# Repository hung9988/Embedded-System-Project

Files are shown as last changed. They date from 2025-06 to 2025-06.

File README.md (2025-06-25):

# HUST Embedded Systems Project
This is a project for the course of Embedded Systems at HUST.

## Project Overview
This project focus on the design of a analog macro pad using the Blackpill (STM32F411CEU6) microcontroller. 

## Features
- **Analog Output**: The macro pad can output analog signals.
- **Rapid Trigger**: A feature that allows the macro pad to send a signal immediately when a key is pressed, without waiting for the key to be released.
- **USB HID**: The macro pad will be recognized as a Human Interface Device (HID) by the host computer, allowing it to send key presses and other input events.
- **USB CDC**: The macro pad will support USB Communication Device Class (CDC) for serial communication with the host computer.
- **Macro Support**: The macro pad can be programmed to perform specific actions when certain keys are pressed.
## External Links
- [3D Case Design](https://cad.onshape.com/documents/5e6cfea2e32c850f530cae58/w/579554a927bd0a7730e0b539/e/56addd2516469d5755cfe071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)

## Resources

- [How does USB work?](https://www.youtube.com/watch?v=N0O5Uwc3C0o&t=158s)
- [What is Rapid Trigger?](https://www.youtube.com/watch?v=eZENx1T7OLw)

## References

- [Minipad](https://github.com/minipadKB/minipad-firmware)
- [Riskeyboard](https://github.com/riskable/void_switch_65_pct)
- [Macrolev](https://github.com/heiso/macrolev/tree/main)
- [TinyUSB](https://github.com/hathach/tinyusb)
- [USB in a Nutshell](https://www.beyondlogic.org/usbnutshell/usb1.shtml)
- [SSD1306](https://github.com/afiskon/stm32-ssd1306/tree/master)

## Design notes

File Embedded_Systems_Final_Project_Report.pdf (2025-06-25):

HANOI UNIVERSITY OF SCIENCE AND TECHNOLOGY

SCHOOL OF INFORMATION AND COMMUNICATION TECHNOLOGY

### HE16: Hall-Effect Keyboard

EMBEDDED SYSTEMS

COURSE: IT4210E — CLASS CODE: 156819 — SEMESTER 2024.2

Le Ngoc Quang Hung | 20225975 | hung.lnq225975@sis.hust.edu.vn
Tran Quang Hung | 20226045 | tuan.tp22h6045@sis.hust.edu.vn
Tuong Phi Tuan | 20226069 | tuan.tp226069@sis.hust.edu.vn

Submitted to: Professor Ngo Lam Trung

Hanoi - 2025

Contents

1 Introduction | 3
2 Design | 5
3 Setup and Implementation | 17

Glossary

Term | Definition
Hall-Effect sensor | Sensors that detect magnetic fields and convert them into electrical signals.
Hall-Effect switch | A type of contactless switch that uses a magnet and a Hall effect sensor to detect key presses based on the mag-netic field strength.
Actuation point | The depth at which a keypress is registered/unregistered and a signal is sent to the computer. In mechanical switches, this is the fixed point where metal contacts close the circuit. In Hall-Effect switches, it can be ad-justed via firmware.
HID(Human Interface Device) | A class of devices that interact with humans, like key-boards, mice. In USB, it defines a protocol for such in-teractions.
CDC(Communications Device Class) | A USB class to emulate serial ports, allowing microcon-trollers to communicate via a virtual COM port.
Rapid Trigger | A feature allowing keys to reset and re-register quickly, enabling faster repeated input without returning to the original actuation point.
Macro | A sequence of key presses/actions recorded and replayed with a single key.
EWMA (Exponentially Weighted Moving Aver-age) | A smoothing algorithm that weights recent data points more heavily to reduce noise.
USB descriptor | Structured USB data describing the device’s capabilities (e.g., interfaces, endpoints) used during enumeration.
Snaptap | Only one key is allowed to be pressed at a time (single-key rollover, ”snaptap” style like in certain mechanical keyboards); when a new key is pressed, the previous key is automatically released.

### 1. Introduction

1.1. Project Description

The goal of this project is to recreate a basic version of an analog Hall-Effect keypad, offering a wider range of functionality compared to traditional keypads. Traditional keypads commonly rely on a keyboard matrix to detect button presses, where each key is either in an ON (HIGH) or OFF (LOW) state. These inputs are then translated to HID signals that a computer can interpret.

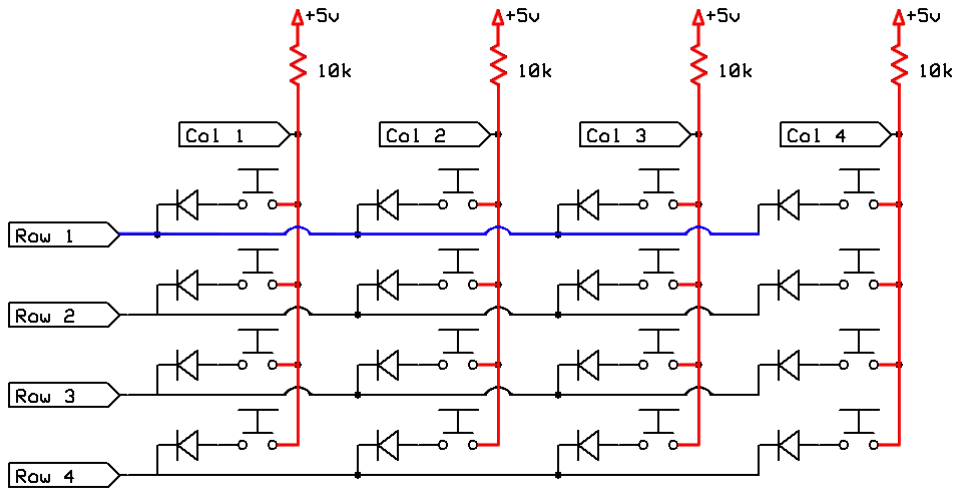
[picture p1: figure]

Figure 1: A keyboard matrix

In contrast, this project replaces the standard mechanical switches with Hall-Effect sensors and magnetic key switches. Unlike typical digital switches that only detect binary states (pressed or not pressed), Hall-Effect sensors provide a continuous analog voltage corresponding to the distance between a magnet and sensor which in this case, is how far the key is pressed.

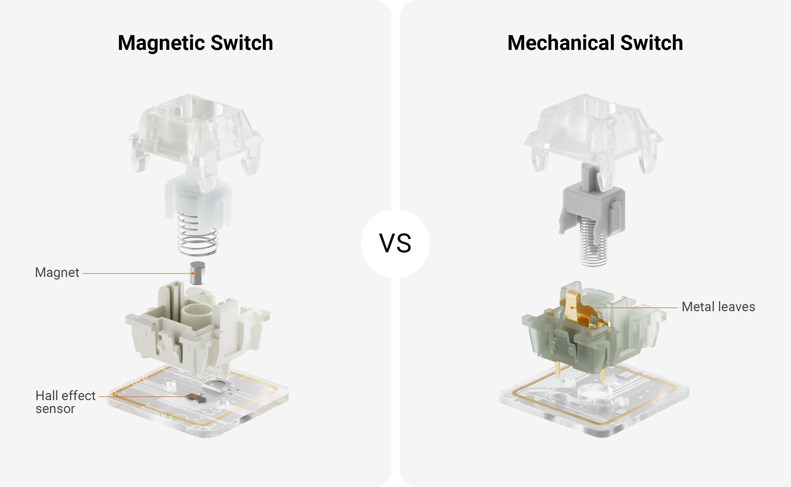
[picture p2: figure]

Figure 2: Structure of a magnetic switch and a mechanical switch

Since the Hall sensor outputs an analog signal, it enables a finer level of input control. This makes it ideal for tasks requiring variable input, such as joystick movement, pressure-sensitive key presses, or velocity-based control in digital instruments and gaming environments.
Moreover, since there are fewer mechanical parts (no metal leaves and output pins) in magnetic switches, there are fewer points of failure, helping with the durability of the board.
1.2. Project Requirements
1.2.1. Functional Requirements

The keypad supports the following functionalities:

- Detect analog signals from the Hall-Effect sensors based on how deep the switches are pressed and translate them into HID inputs.
- Support rapid trigger, which is a feature often found in analog gaming keyboards that uses analog sensing to detect key positions continuously. Instead of waiting for keys to fully reset before registering another press, they can start registering again as soon as they start moving upward. This allows for much faster repeated input than traditional mechanical switches.
- Support macro functions, allowing users to assign sequences of keystrokes to a single key for automated execution of complex actions.

- Operate as a composite USB device with the following interfaces:

– A HID interface for key input.

– A CDC interface for configuration and debugging.

- Provide a debug and configuration interface over a serial protocol (via the CDC interface), eliminating the need to recompile the firmware for changes.
- Provide an auto calibration method to compensate for inherent signal differences between individual sensors, ensuring consistent key behavior across the keypad.
- Display key states and modifier activity using the SSD1306 OLED screen.
1.2.2. Non-Functional Requirements
- Include appropriate analog filtering (e.g., low-pass filter and software filter) to stabilize sensor outputs. For hardware filter, voltage fluctuations must fall within ±10 mV. .
- Support a polling rate of 1 kHz, the keyboard must spend at most 1 tick (1ms) to complete a loop.

### 2. Design

2.1. Function Assignments
Function | Hardware | Software
Detect Analog Signals and Translate them into HID Inputs | Yes | Yes
Rapid Trigger | No | Yes
Macro | No | Yes
Composite USB Device | No | Yes
Debugging interface | No | Yes
Analog filters | Yes | Yes
1 kHz polling rate | No | Yes
Calibration method | No | Yes
2.2. Hardware Design

For the hardware,a PCB is used instead of a breadboard to minimize electrical noise that could interfere with the sensors. Additionally, some components are only available in surface-mount (SMT) packages, which are better suited for PCB integration.

System Schematic

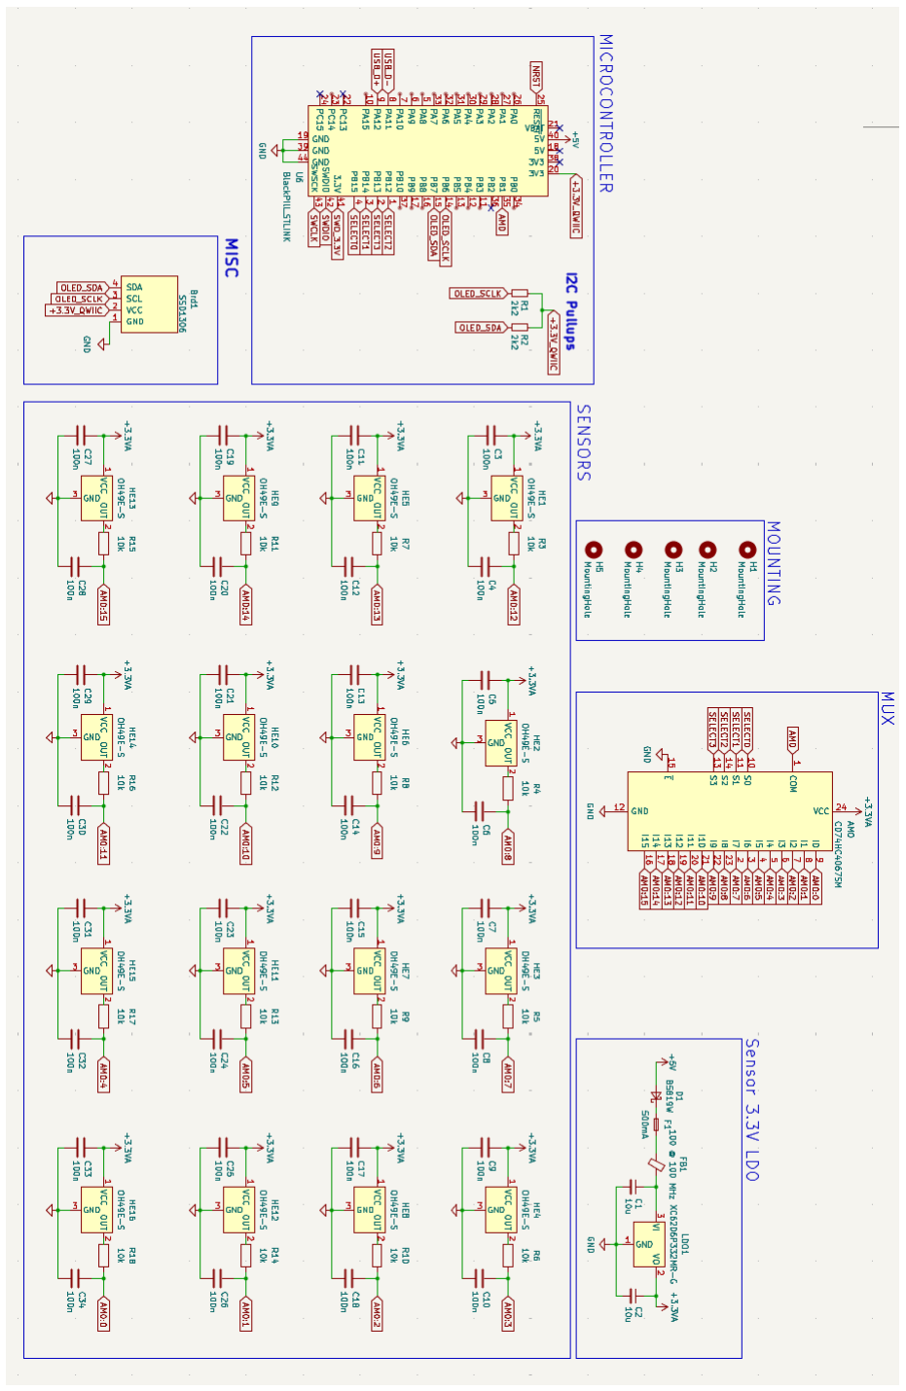
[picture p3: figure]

PCB Design

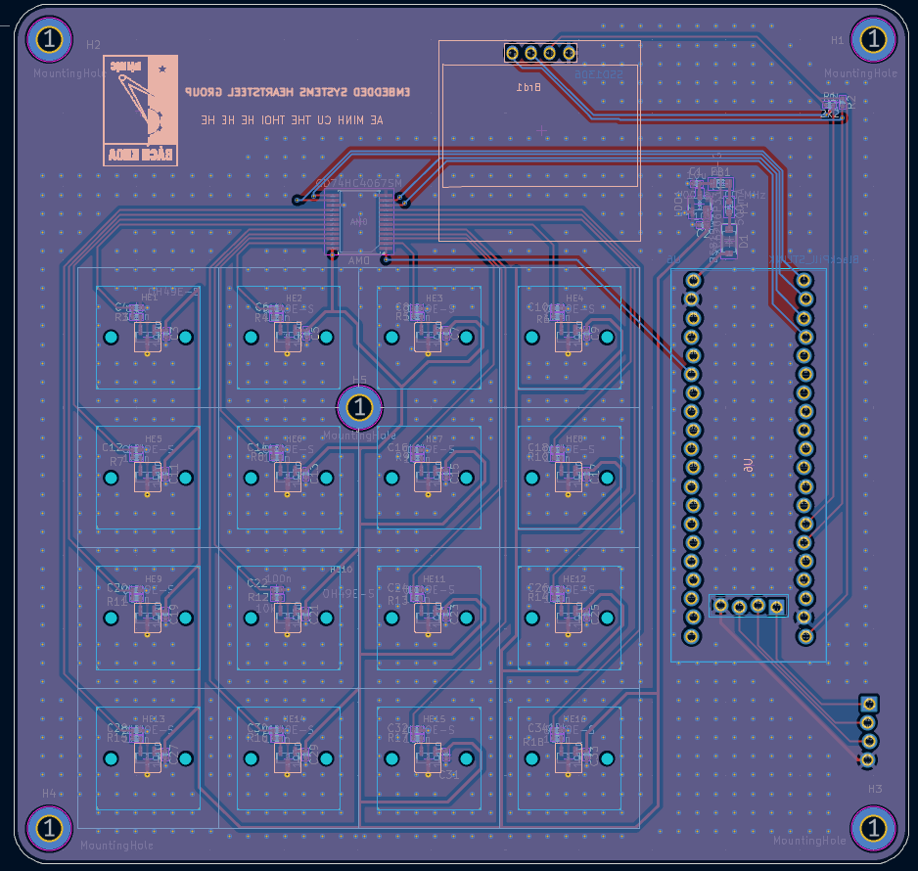
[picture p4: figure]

3D View Front

3D View Back

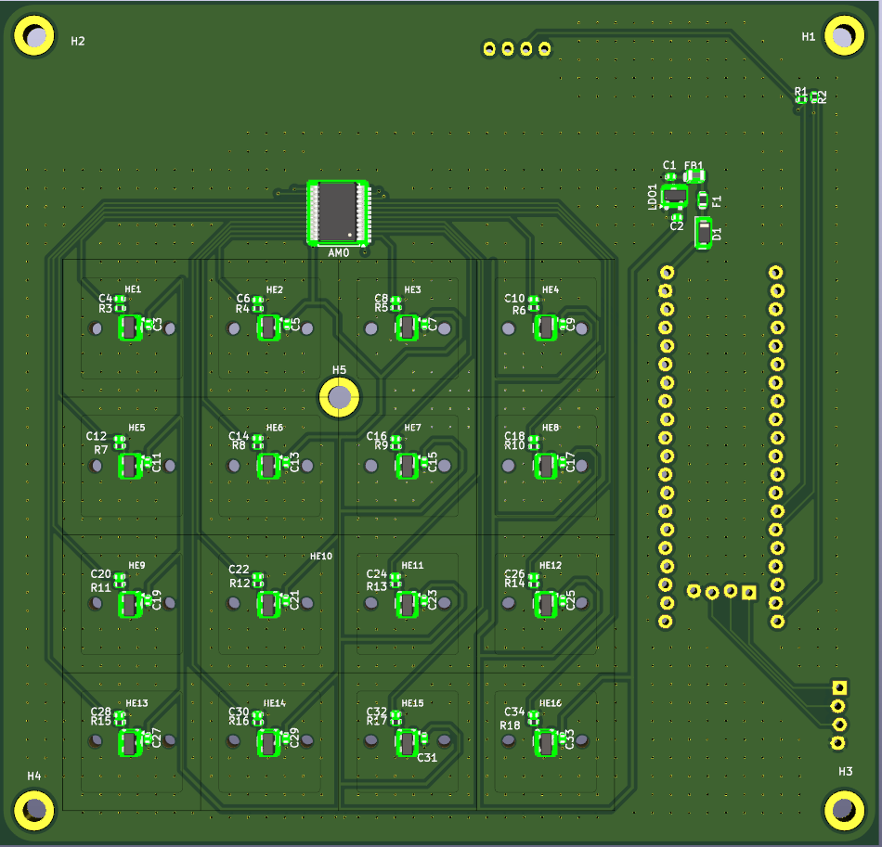
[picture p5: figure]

Final Product

Components

Component | Description | Datasheet
STM32F411CEU6 WeAct Blackpill Kit | A compact development board based on the STM32F411CEU6 ARM Cortex-M4 microcontroller. | ST Datasheet (https://www.st.com/resource/en/datasheet/stm32f411ce.pdf)
SSD1306 OLED Display | Standard 128x64 OLED display. | SSD1306 Datasheet (https://cdn-shop.adafruit.com/datasheets/SSD1306.pdf)
XC6206P332MR-G | A 3.3V low dropout voltage regulator used to step down and regulate power supply. Provide a stable analog power source for the sensors. | XC6206 Datasheet (https://lcsc.com/datasheet/lcsc_datasheet_2304140030_Torex-Semicon-XC6206P332MR-G_C5446.pdf)
CD74HC4067SM96 | A 16-channel analog multi-plexer/demultiplexer. Used to expand the number of analog inputs to the micro-controller, allowing multiple Hall effect sensors to be read using fewer ADC pins. (On the board, all 16 analog sensors can multiplex into only one ADC pin) | CD74HC4067 Datasheet (https://lcsc.com/datasheet/lcsc_datasheet_2410121934_Texas-Instruments-CD74HC4067SM96_C98457.pdf)
OH49E-S | A linear Hall-Effect sensor that outputs an analog voltage proportional to the mag-netic field strength. Used to detect the po-sition of a magnet in magnetic switches. | OH49E Datasheet (https://www.progrexa.com/file_PDF/OH49E.pdf)
Gateron KS-20 | A magnetic key switch designed to be used with Hall effect sensors. | Gateron Datasheet (https://gateron.com/u_file/2312/26/file/GATERONMagneticOrangeSwitch-KS-20TO10B050NW-Y64.pdf)

Microcontroller

The STM32F411CEU6 microcontroller is chosen mostly for its low price and decent performance. It also supports I2C and USB 2.0 full-speed protocols, which is enough for the scope of this project.

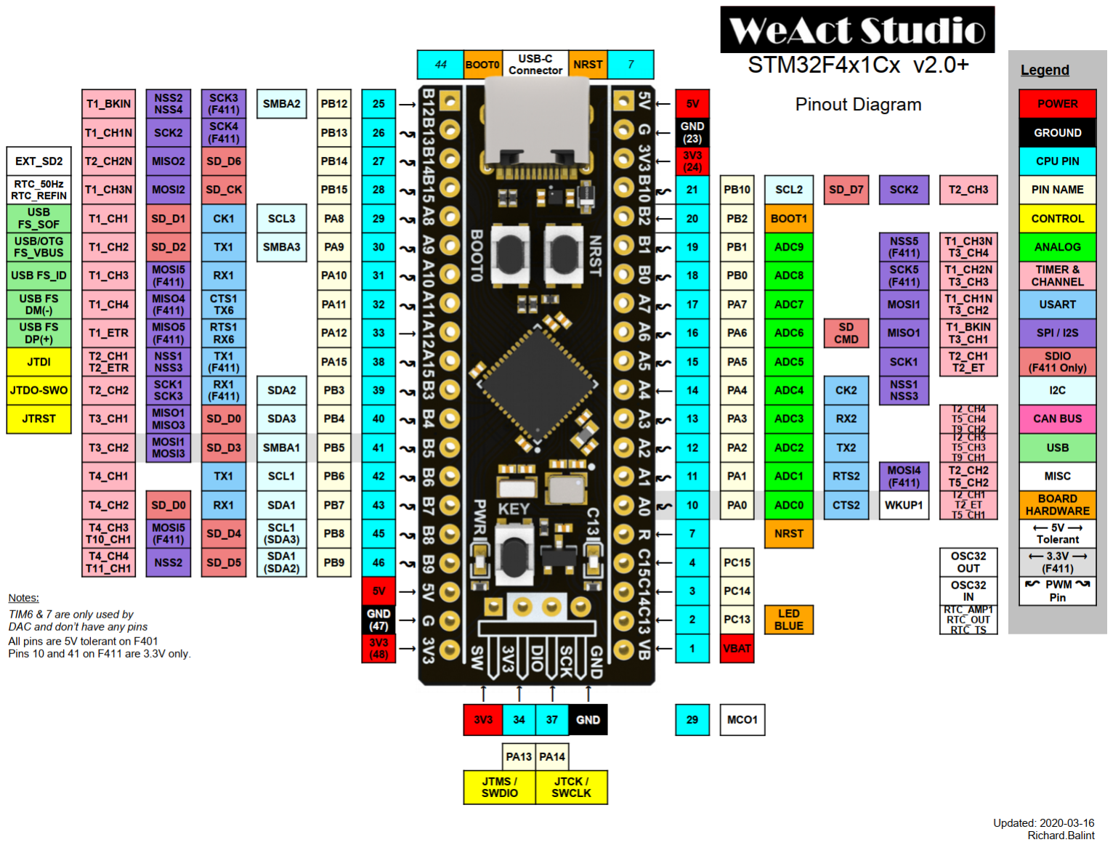
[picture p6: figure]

Figure 3: WeAct STM32F411CEU6 Blackpill

Two pull-up resistors are also connected to the I2C pins to pull them high since I2C devices can only drive the line low and cannot pull the line up themselves.

Power Supply

To minimize noise and ensure reliable analog signal, the system uses two separate 3.3V power sources for digital and analog domains:

- 3.3V QWIIC: This is the default 3.3V supply provided by the development board (e.g., STM32 Blackpill). It powers digital components such as the OLED display and other logic-level devices.
- 3.3VA: This is a clean 3.3V analog supply generated by the LDO regulator (e.g., XC6206P332MR-G). It provides a more stable and noise-isolated voltage, used only for analog-related components, such as the Hall effect sensors and the analog multiplexer (e.g., CD74HC4067).

Sensor

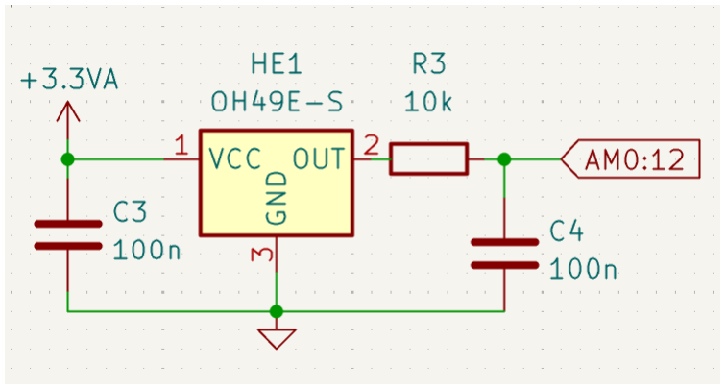
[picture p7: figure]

For each sensor, we connect a decoupling capacitor to the VCC pin to stabilize the power supply and reduce voltage ripples. On the output pin, we add an RC low-pass filter to suppress high-frequency noise.
The frequency of the changes in the output of the sensor depends on human input, which is not very fast. Following the RC filter formula, the cutoff frequency of 159Hz (R is 10kOhm and C is 100nF) is chosen, which can still comfortably let human input pass, but other high frequency signals will be heavily attenuated.

Multiplexer

The Blackpill only has 10 analog pins while the keypad has 16 keys. A multiplexer is needed to read all 16 sensors.
The CD74HC4067 is chosen because it is cheap, easy to find, has exactly 16 channels, and there is a DIP version of the module to experiment with before the PCB is ordered.
There are 4 select lines corresponding to 4 selection bits on this module which can be used to select the appropriate channel. For example, if all lines are in LOW state then the 4-bit value is 0000 -¿ channel 0 is selected.

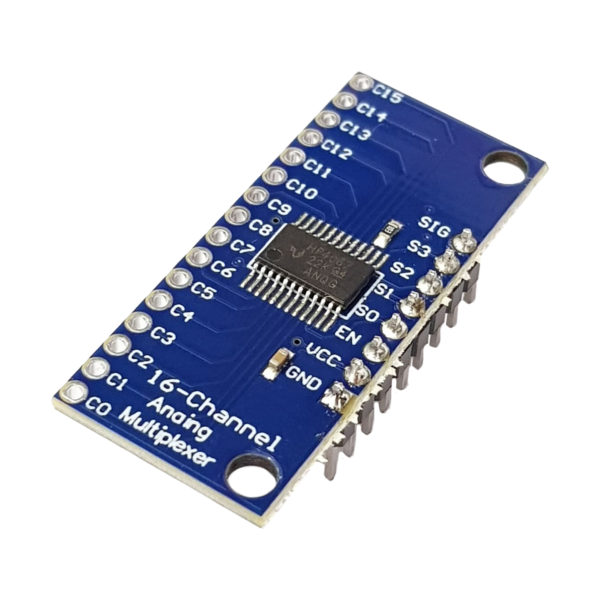
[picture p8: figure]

Figure 4: DIP version of the CD74HC4067.

Miscellaneous

An extra I2C 128x64 OLED display and SWD debug pins are also added.

2.3. Software Design
Module | Description
config | Hold the default configurations for the keyboard such as number of mul-tiplexers, number of channels, actuation point offset and more.
main | The main program entry point, responsible for hardware initialization (GPIO, ADC, I2C, USB), and calling the main keyboard processing loop.
keyboard | Implements the core keyboard logic, including managing key states, detecting and processing key presses.
USB | Handling communication through USB using TinyUSB stack.
HID | Submodule of USB, manages the USB HID (Human Interface Device) communication for the keyboard.
CDC | Submodule of USB, manages the USB CDC (Communication Device Class) communication, mainly used to config and debug the board.
OLED | Manage SSD1306 display, handles drawing to a buffer and updates screen.

2.4. System Flow Chart

State machine diagram for key status

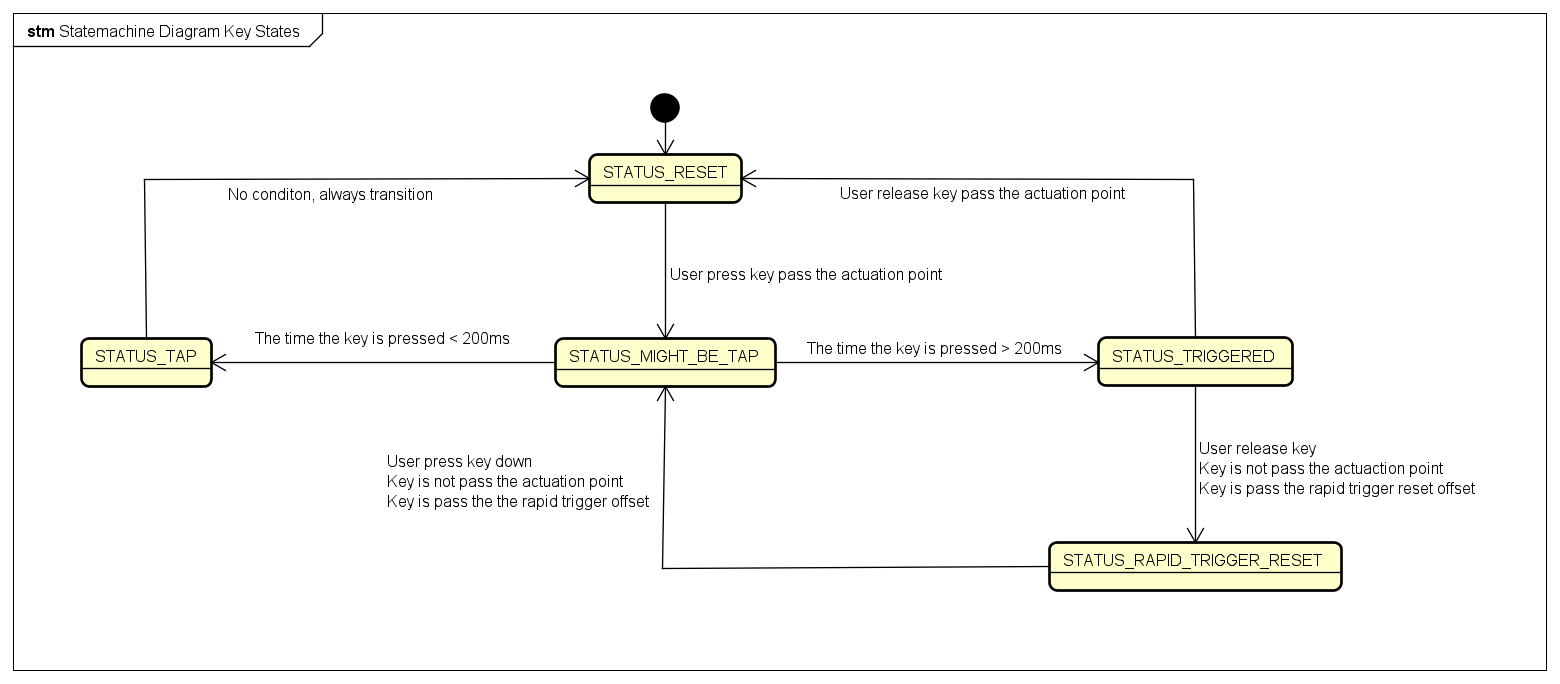
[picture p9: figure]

Main Loop

Keyboard Task

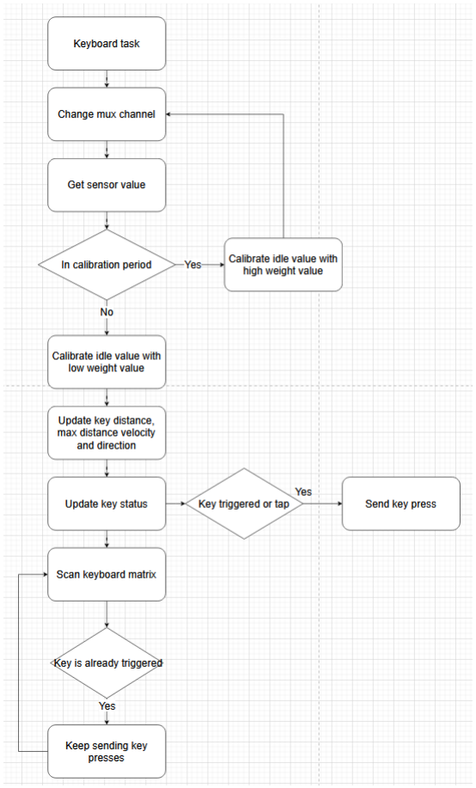
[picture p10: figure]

HID Task

CDC Task

Even though STM32CubeIDE has its own implementation of a USB stack, it does not support building USB composite devices (HID + CDC). Instead, TinyUSB stack is used.
In order to get a composite USB device to work, appropriate descriptors are needed. The image below is an overview of the project’s USB descriptors.

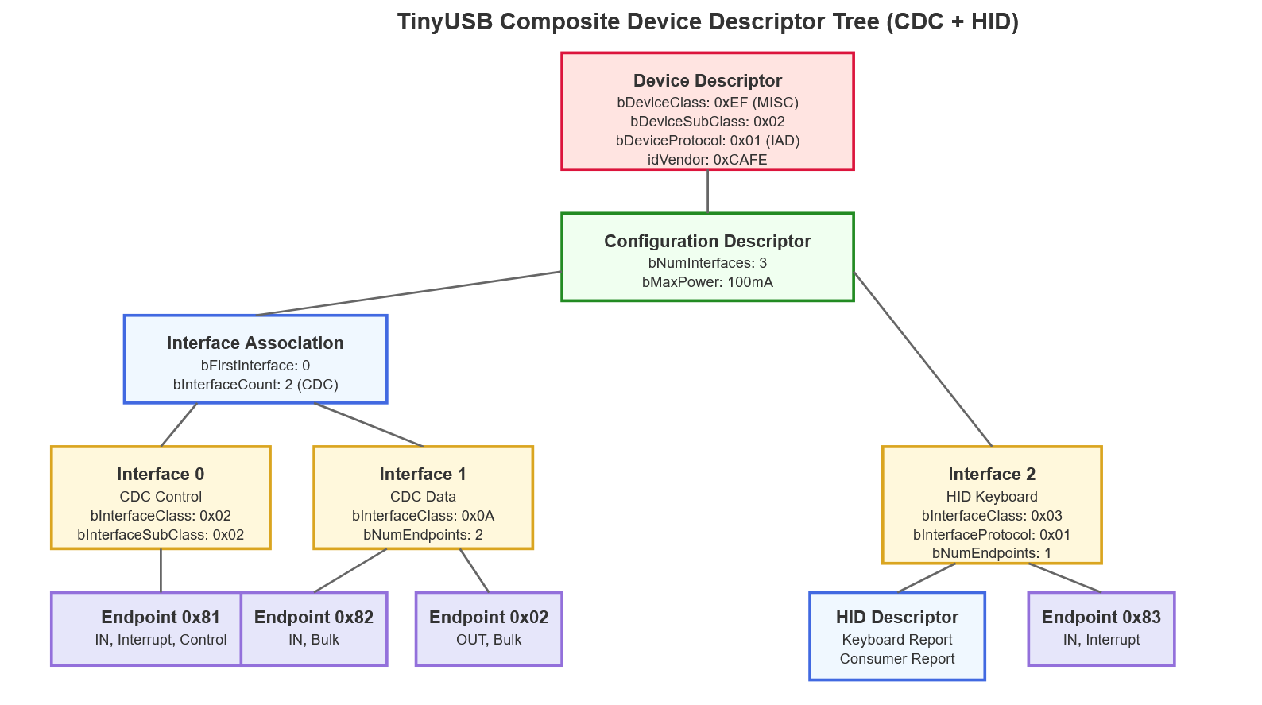
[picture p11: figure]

There are 3 interfaces:

- CDC Control interface: This interface handles the control and configuration of the USB CDC device. It is used for tasks like setting line encoding (baud rate, parity, stop bits), controlling the line state (e.g., DTR, RTS), and managing class-specific requests from the host.
- CDC Data: This interface handles the actual data transmission between the USB host and the device for the CDC class. It consists of separate endpoints for IN (device-to-host) and OUT (host-to-device) bulk data transfer.
- HID interface: This interface is used for Human Interface Devices like keyboards, mice, and game controllers. It includes a report descriptor that defines the format of the data sent to and from the device. Communication typically happens through interrupt endpoints for low-latency, small-packet data exchange.

OLED Task

dadad ˆ

### 3. Setup and Implementation

The complete source code have been uploaded to GitHub: Embedded System (https://github.com/hung9988/Embedded-System-Project)

3.1. Keyboard
3.1.1. Algorithm Overview

The general algorithm used for the keyboard is based on the travel distance of each key, which is how far the key is pressed down. For this particular magnetic switch, the travel distance ranges from 0 to 4mm.

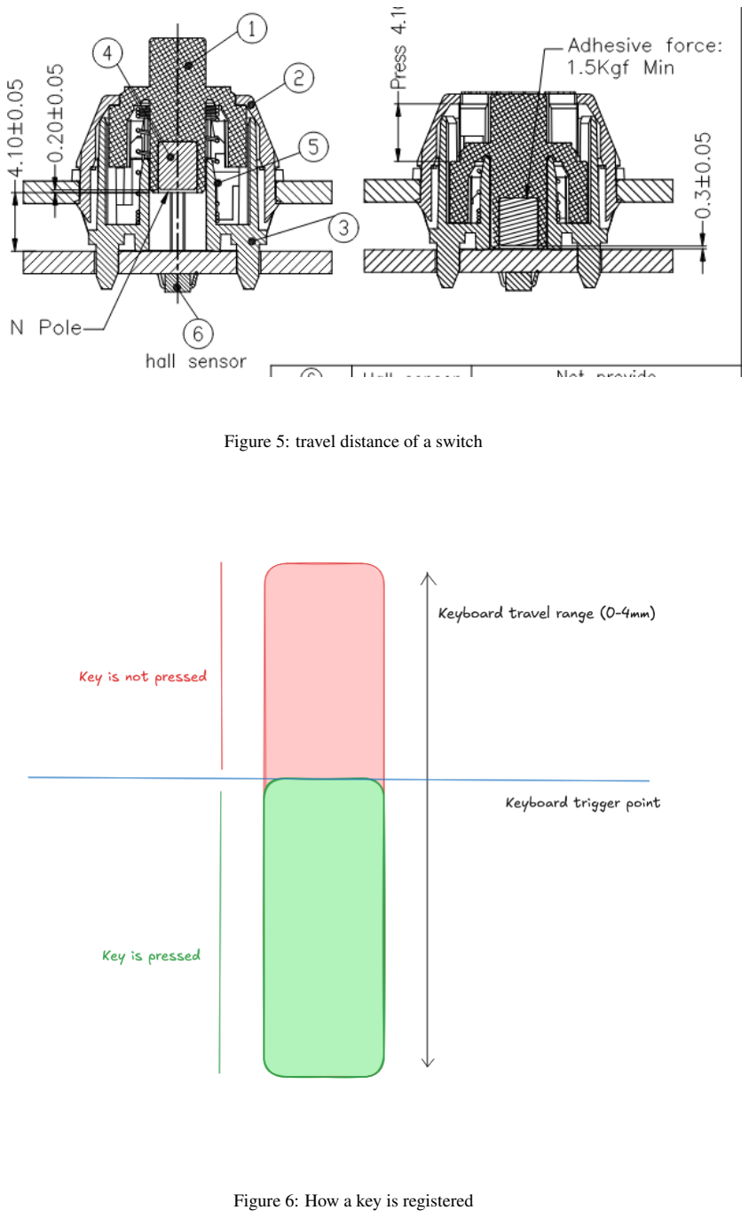
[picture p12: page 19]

Figure 5: travel distance of a switch

Figure 6: How a key is registered

At its core, a specific distance value is defined as the trigger point. When the key’s travel distance passes this point, it is registered as a key press.
The rapid trigger algorithm works a bit differently. Instead of relying on a fixed trigger point, it uses the moment when the direction of key movement changes (i.e., from moving up to down or vice versa). This creates a temporary, dynamic trigger point closer to the key’s current position, enabling much faster key registration and release.
3.1.2. Keyboard Implementation

The Key data structure is used to store data about a key, including:

- is enabled: the key activation status, disabled keys will be skipped during scanning.
- row, column: the position of the key in the keyboard matrix, used to assign keymaps and appropriate channels on the multiplexer.
- is idle: indicates whether the key is in the idle (not pressed) state.

Keymap Layers

A key can have multiple keymaps on multiple layers. For each layer, a key has:

- type: The type of key, which can be:

– KEY TYPE EMPTY: Default state, mapped to nothing.

– KEY TYPE NORMAL: Normal keys (e.g., A, B, 1, 2, 3).
– KEY TYPE MODIFIER: Modifier keys (e.g., Shift, Ctrl, Alt).
– KEY TYPE CONSUMER CONTROL: OS-specific consumer control keys (e.g., VOLUME UP, VOLUME DOWN on Windows).
– KEY TYPE MACRO: Macro keys containing a list of keycodes (e.g., Ctrl+Shift+P).
- value: An array of hexadecimal values representing keycodes (e.g., 0x04 for ‘A’).

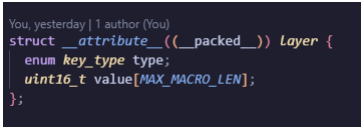
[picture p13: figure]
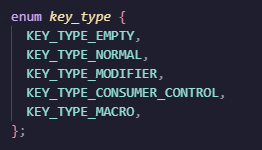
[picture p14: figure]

Calibration Data

Used to store data for calibration purposes:

- cycles count: Total number of calibration cycles.

- idle value: The key value when not pressed; recalibrated continuously. Used as the reference for calculating distance.
- max distance: Maximum distance recorded relative to idle value. Represents the sensor value difference from idle to fully pressed.

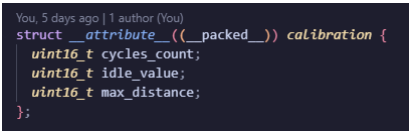
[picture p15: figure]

Key State

Stores the current state of the key:

- value: Current sensor value.
- distance: Difference from idle value (e.g., idle = 1800, current = 2100, distance = 300).
- filtered distance: Distance after EWMA filtering.
- * 8bits: are the same values as the original variables but cast to 8 bits to limit the value range, reducing noise impact and enable a bit more efficient calculation.
- velocity: Rate of key press or release, calculated based on the difference in the new and old value of filtered distance 8bits.

Actuation Data

Stores the status and configuration of the key:

- direction: Current direction (up or down), inferred from the sign of velocity.
- direction changed point: Value recorded at the last direction change, used in rapid trigger logic.
- status: Key status, which can be:

– STATUS MIGHT BE TAP: Intermediate state, transitions to STATUS TAP or STATUS TRIGGERED depending on timing (if the key is pressed for less than a timeout value, it is a STATUS_TAP, otherwise it is a STATUS_TRIGGERED).

– STATUS TAP: One of two final status of a key, key press is sent and released immediately.

– STATUS TRIGGERED: One of two final status of a key, Key press is sent, but release may be delayed depending on if the user continue to hold the key or not.

– STATUS RESET: Default state when not pressed.

– STATUS RAPID TRIGGER RESET: A key will reach this status when it passes the rapid trigger reset threshold, which allows the key to enter STATUS_TAP or STATUS_TRIGGERED state again without returning to STATUS_RESET first.

- trigger offset: Acts as the configurable actuation point. When distance exceeds this, the key is considered pressed.
- reset offset: Defines the release point. When distance drops below this, the key is considered released.

In mechanical switches, actuation and release points are usually the same. However, in this analog implementation, reset offset is set slightly lower than trigger offset to account for hysteresis, which prevents input chatter and accidental
key toggles during small fluctuations around the threshold.
- rapid trigger offset: Similar to trigger_offset, but instead of being referenced from the idle_value, this offset is measured from the direction_changed_point, which is the position where the finger starts pressing down after moving upward
(or vice versa) while still staying below the triggered_offset.

This function enables faster re-triggering during rapid key taps or oscillations by dynamically adapting the actuation point based on movement direction, improving responsiveness.

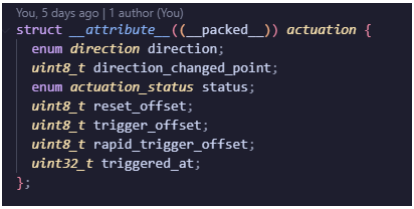
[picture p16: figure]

3.1.3. An example keyboard configuration

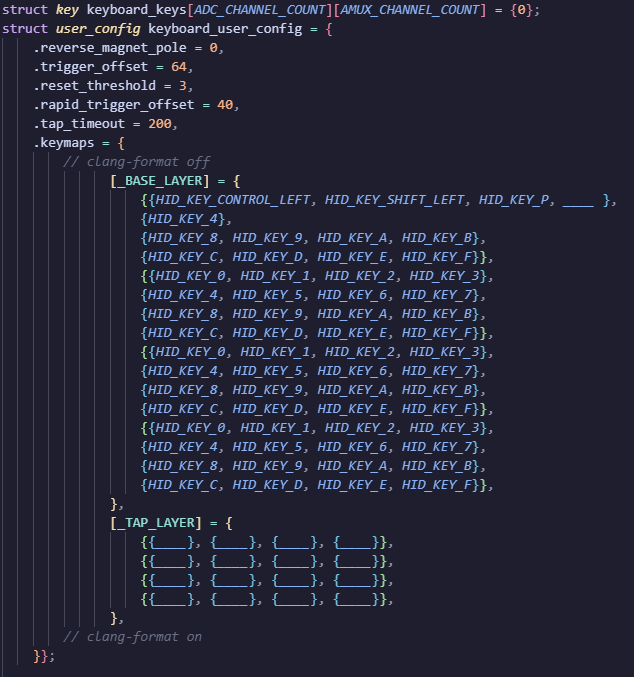
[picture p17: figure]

reset_offset is calculated on the basis of trigger_offset and reset_threshold: RESET_OFFSET = TRIGGER_OFFSET – RESET_THRESHOLD

3.1.4. Functions of the module

Name | Description
uint8 t get bitmask for modifier (uint8 t keycode) | Returns a bitmask with one bit set corre-sponding to the given modifier keycode (e.g., Ctrl, Shift). If the keycode is not a modifier, it returns 0x00. Used to identify and encode modifier keys.
void init key( uint8 t adc channel, uint8 t amux channel, uint8 t row, uint8 t column) | Initializes a key in the keyboard keys ma-trix at the given coordinates. Populates all fields and assigns keymaps to layers based on their type (NORMAL, MODIFIER, CON-SUMER CONTROL, MACRO).
uint8 t update key state( struct key *key) | Reads the raw ADC value from the Hall ef-fect sensor and performs an initial calibration during the first 20 cycles using an EWMA filter with = 0.6 to estimate the idle value. After calibration, the filter continues with = 0.8 to smooth out noise and reduce fluctua-tions. The function then calculates and up-dates the key’s distance, filtered distance, ve-locity, and direction. It also tracks the max-imum observed distance and the direction change point for use in rapid trigger logic.
void update key actuation( struct key *key) | Updates the actuation status of a key based on distance, direction, and thresholds and the current key state. Manages tap detec-tion, key press/release calls, and transitions between RESET, TRIGGERED, TAP, and RAPID TRIGGER RESET.
void update key( struct key *key) | Combines update key state() and update key actuation() to perform a complete update on a key’s state and actuation logic. If the key is not ready (e.g. still calibrating), it does nothing.
void keyboard init keys() | Loops through the key matrix and initial-izes all keys using init key() where where channel data is valid.(there is a channel mapped to that key).
void keyboard task() | Main loop called in each cycle. Iterates through all enabled keys, reads input, updates state and actuation, and handles key press and hold logic.
void keyboard task() | Main loop called in each cycle. Iterates through all enabled keys, reads input, updates state and actuation, and handles key press and hold logic.
void snaptap task() | keyboard task() with additional logic to release the old key if a different key is pressed. This task is used for gaming pur-poses.

3.2. USB
3.2.1. HID
Name | Description
void hid task() | Sends HID reports (keyboard or consumer control) over USB when should send * flags are set and the USB device is ready.
void hid press key( struct key *key, uint8 t layer) | Handles the logic to press a key. Depend-ing on the key type (modifier, normal, macro, consumer control), it sets the correspond-ing USB HID report fields (modifiers, keycodes[], or consumer report) and sets flags to indicate a report should be sent. For macros, it processes both modifier and normal parts, ensuring they fit within the 6-key rollover limit.
void hid release key( struct key *key, uint8 t layer) | Reverses the effect of hid press key, clear-ing the modifier bits, keycodes, or consumer report as appropriate. Also processes all keys in a macro, releasing both modifier and nor-mal parts.
3.2.2. CDC

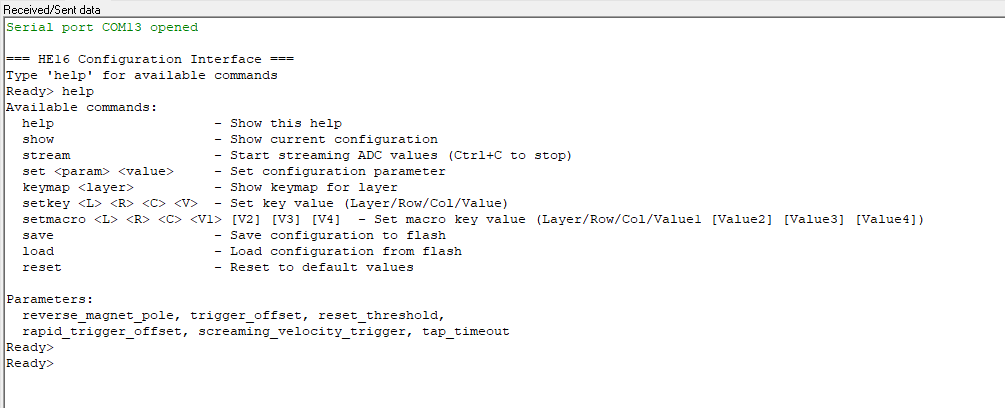
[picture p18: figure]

Figure 7: Available configuration and debugging commands

Name | Description
void cdc task(void) | Main handler for USB CDC input. Reads and parses user input over serial. Handles control characters (backspace, enter, Ctrl+C), echoes input, and processes commands. Accommo-dates the basic functions of a terminal.
void cdc performance measure( uint32 t started at) | Calculates the elapsed time since started at using HAL GetTick() and sends it to the host over CDC. Used to measure the performance of the system.
static void handle streaming(void) | Sends periodic ( 1kHz) CSV-formatted ADC value of the sensors.
static void start streaming(void) | Activates sensor value streaming and notifies the user.
static void stop streaming(void) | Stops sensor value streaming.
static void process command(char *cmd) | Parses a command string and dispatches it to corresponding actions like set, keymap, save, load, reset, etc.
static void print help(void) | Sends a help message listing all available commands and configuration parameters.
static void print config(void) | Sends the current user config values (e.g. trigger thresholds, timeouts, etc.) to the user over CDC.
static void set config value (char *param, char *value) | Parses and sets a configuration parameter in the keyboard user config based on user input.
static void print keymap(uint8 t layer) | Prints the full keymap of the given layer, in-cluding macro formatting for keys with mul-tiple values.
static void set keymap value( uint8 t layer, uint8 t row, uint8 t col, uint16 t value) | Sets a single key’s value in the keymap and clears any existing macro values. Also writes to flash and reinitializes keys.
static void set macro keymap value( uint8 t layer, uint8 t row, uint8 t col, uint16 t values[MAX MACRO LEN]) | Sets macro values for a key which contains multiple keycodes. Writes to flash and reini-tializes the key matrix.
static void save config(void) | Saves the current user config to flash memory.
static void load config(void) | Loads user config from flash memory and reinitializes the key matrix.
static void reset config(void) | Restores configuration to default values from keyboard default user config, saves to flash, and reinitializes keys.
static void cdc write string chunked (const char *str) | Writes a string to CDC output in manageable chunks to prevent buffer overflow.
static void cdc write flush wait(void) | Flushes the CDC buffer and waits until all data is sent. Ensures message delivery.

3.3. OLED
Name | Description
void ssd1306 Init(void) | Initializes the OLED display by configur-ing addressing mode, orientation, contrast, charge pump settings, and display dimen-sions. Clears the buffer and flushes it to the screen.
void ssd1306 UpdateScreen(void) | Efficiently pushes only the changed parts of the screen buffer to the display via I²C/SPI. Tracks modified pages and columns to reduce communication latency.
void ssd1306 Fill(SSD1306 COLOR color) | Fills the entire display buffer with the speci-fied color (either all black or all white).
void ssd1306 DrawPixel(uint8 t x, uint8 t y, SSD1306 COLOR color) | Sets or clears a pixel at the given (x, y) coor-dinate in the buffer.
char ssd1306 WriteChar(char ch, SSD1306 Font t Font, SSD1306 COLOR color) | Draws a single character using the specified font and color at the current cursor position in the screen buffer.
char ssd1306 WriteString(char* str, SSD1306 Font t Font, SSD1306 COLOR color) | Writes a string to the buffer by printing char-acters one after another using the selected font.
void ssd1306 SetCursor(uint8 t x, uint8 t y) | Sets the internal cursor position (used by text functions) to the specified screen coor-dinates.
void ssd1306 DrawRectangle(uint8 t x1, uint8 t y1, uint8 t x2, uint8 t y2, SSD1306 COLOR color) | Draws the outline of a rectangle using straight lines between corners.
void ssd1306 FillRectangle(uint8 t x1, uint8 t y1, uint8 t x2, uint8 t y2, SSD1306 COLOR color) | Draws a filled rectangle of the given bounds and color.
void ssd1306 DrawBitmap(uint8 t x, uint8 t y, const unsigned char* bitmap, uint8 t w, uint8 t h, SSD1306 COLOR color) | Draws a bitmap image onto the screen buffer at the specified coordinates.

void ssd1306 Line(uint8 t x1, uint8 t y1, uint8 t x2, uint8 t y2, SSD1306 COLOR color) | Draws a straight line between two points us-ing Bresenham’s line algorithm.
void ssd1306 DrawCircle(uint8 t par x, uint8 t par y, uint8 t par r, SSD1306 COLOR par color) | Draws the outline of a circle using integer math.
void ssd1306 FillCircle(uint8 t par x, uint8 t par y, uint8 t par r, SSD1306 COLOR par color) | Draws a filled circle by calculating pixel po-sitions within the radius.
void ssd1306 DrawArc(uint8 t x, uint8 t y, uint8 t radius, uint16 t start angle, uint16 t sweep, SSD1306 COLOR color) | Draws an arc (part of a circle) based on start and sweep angle.
void ssd1306 DrawArcWithRadiusLine( uint8 t x, uint8 t y, uint8 t radius, uint16 t start angle, uint16 t sweep, SSD1306 COLOR color) | Draws an arc with connecting radius lines, forming a pie-slice shape.
SSD1306 Error t ssd1306 InvertRectangle(uint8 t x1, uint8 t y1, uint8 t x2, uint8 t y2) | Inverts the pixel colors in a rectangular re-gion by toggling corresponding bits in the screen buffer.
void ssd1306 SetContrast(uint8 t value) | Adjusts the display contrast level by sending a command to the OLED controller.
void ssd1306 SetDisplayOn(uint8 t on) | Turns the display on or off without altering the buffer content.
uint8 t ssd1306 GetDisplayOn(void) | Returns the current display on/off state.
void ssd1306 FlipScreen(uint8 t horz, uint8 t vert) | Changes the horizontal and/or vertical scan direction to flip the screen content.

Each update cycle displays up to six actively pressed keys—three on the top row and three on the bottom. For each key, its hexadecimal keycode and actuation depth (in percentage) are shown. The percentage value is computed from the final filtered analog reading, which results from combining an RC low-pass hardware filter with an EWMA (Exponentially Weighted Moving Average) software filter.

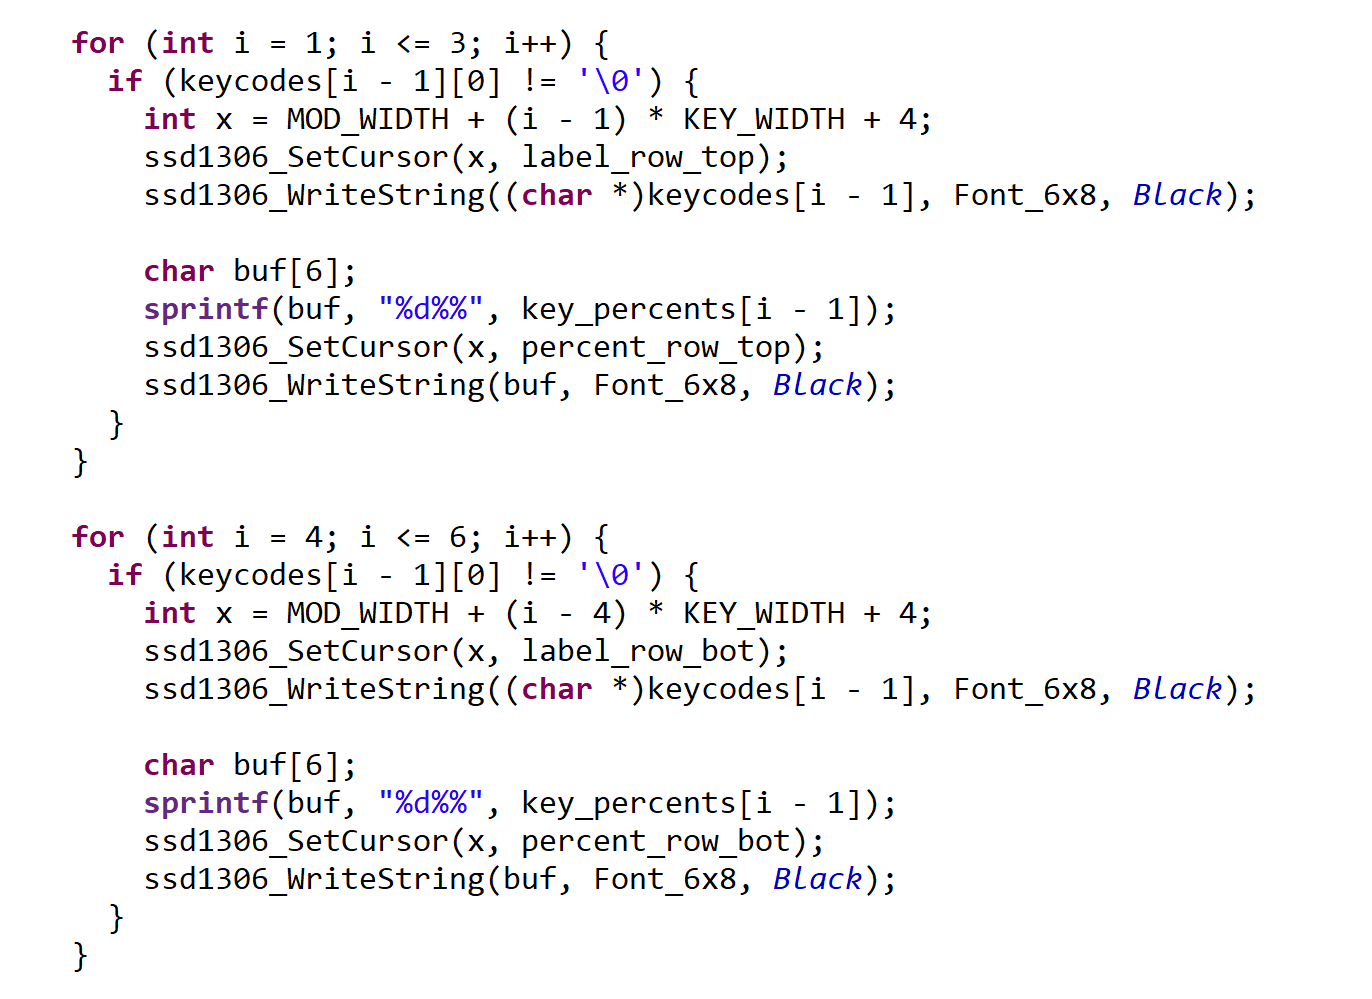
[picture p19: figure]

Modifier keys such as LCtrl, RShift, and LAlt are detected via bitmask values and stored into the buffer for later display on the left side of the screen. Each active modifier will be printed on a new line with vertical spacing managed programmatically.

Each cycle scans all analog key channels to determine which keys are actively pressed and whether they are standard keys or modifiers. For each active key, the system first checks whether the key type is a modifier. If so, it reads the bitmask from the key’s configuration and maps it to a human-readable label (e.g., LCtrl, RShift). If the key is a normal key and fewer than six standard keys have been detected so far, the system stores a hexadecimal representation of the key’s AMUX index. It also calculates the actuation percentage based on the distance 8bits value for later presentation.

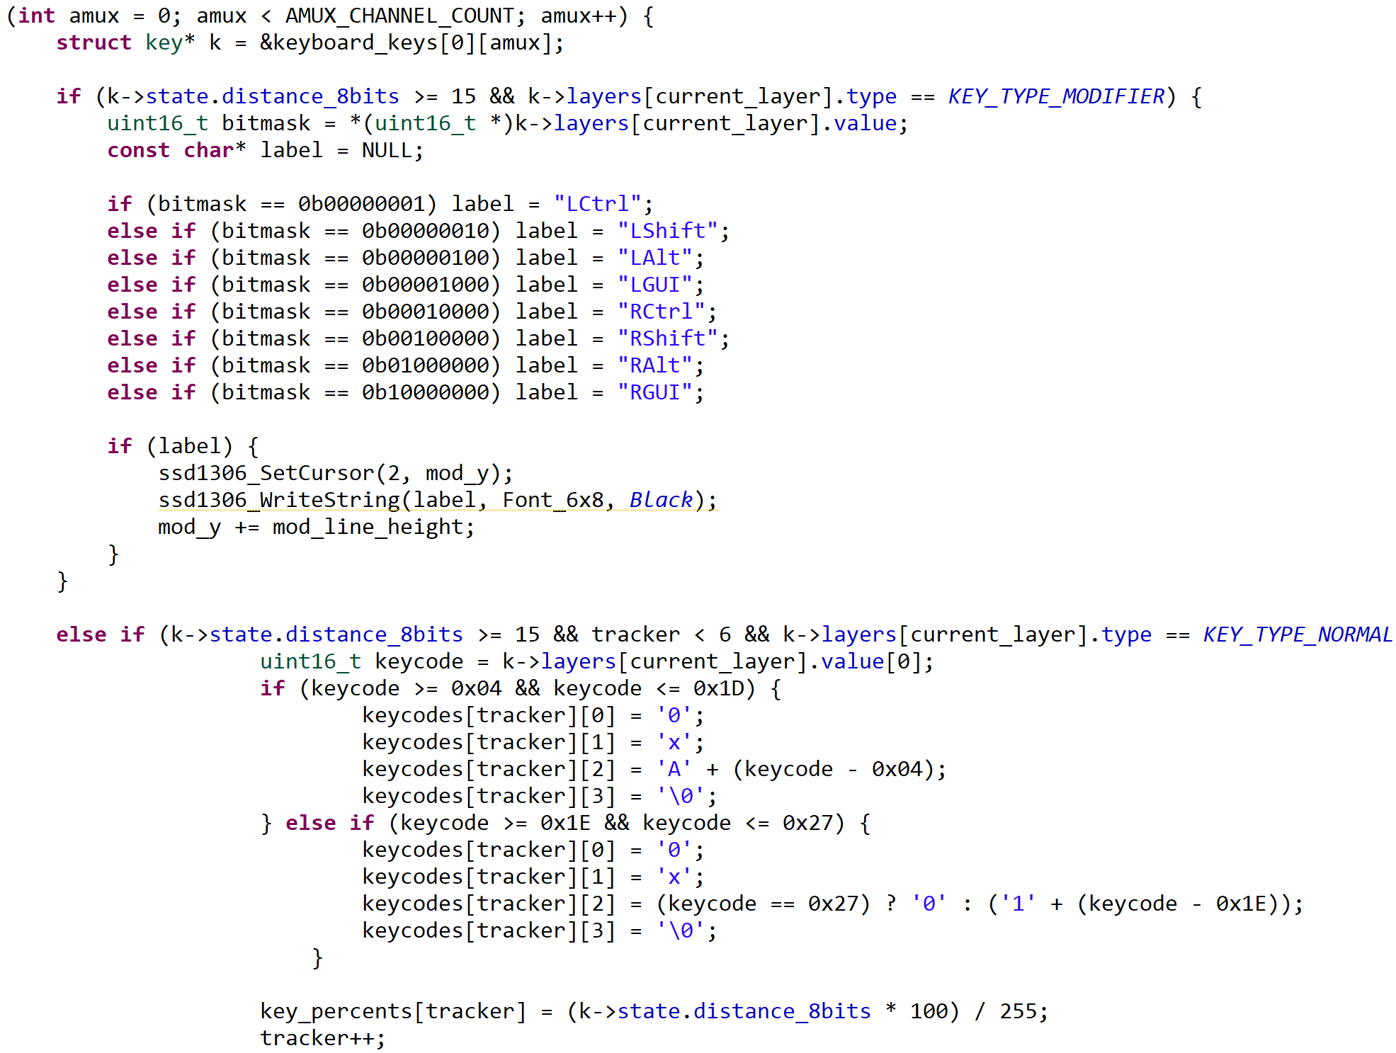
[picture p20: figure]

3.4. Result

The processing time for one cycle (time taken to through all tasks once) can be calculated by getting the time difference between the start and end of the main while loop. After that, the result is printed to the terminal.

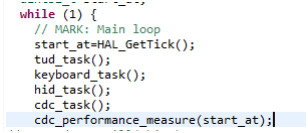
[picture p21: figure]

Figure 8: while loop code snippet

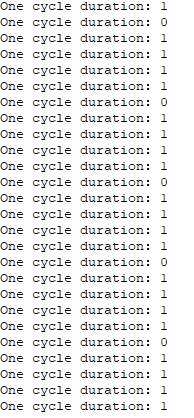
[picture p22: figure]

Figure 9: Cycle duration measurement

The average duration of one cycle is much less than 1 tick (1ms), which satisfies the condition of 1kHz keyboard polling rate.
By using the debugging interface exposed through the Virtual COM Port, the final filtered sensor reading (RC low pass hardware filter + EWMA software filter) can be viewed.

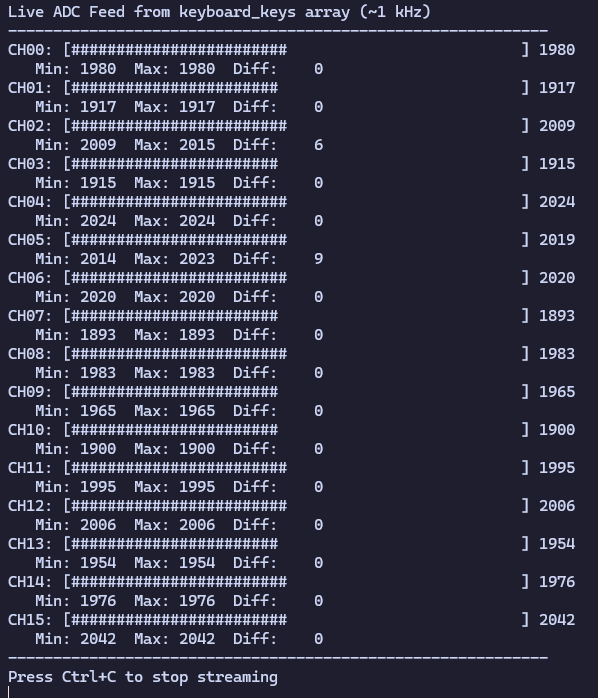
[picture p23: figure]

Figure 10: Value of sensors at idle state

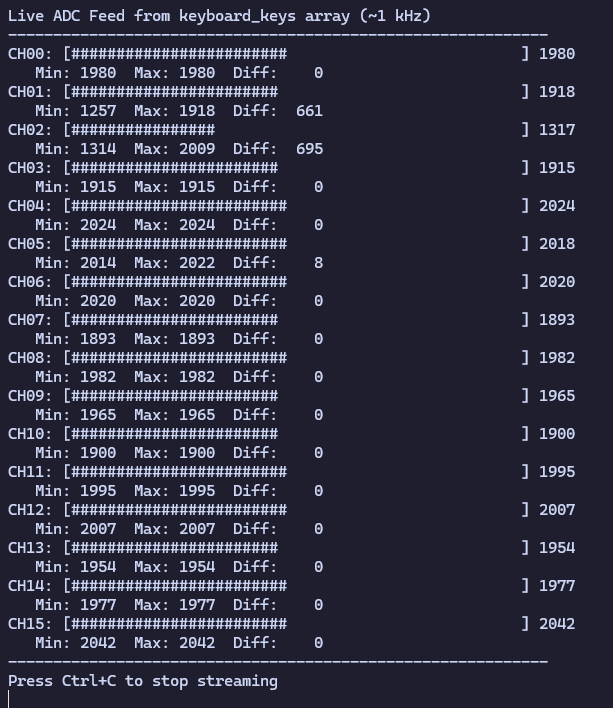
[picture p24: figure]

Figure 11: Value of sensors when fully pressed

The voltage fluctuation at idle_state is very low after filtering.
Both polling rate and sensor output measurement are within the expected value defined in Non-Functional Requirements section.
The complete system test is uploaded to Teams alongside the report.

3.5. Contribution
Name | Task
Le Ngoc Quang Hung | Hardware and software designs. Codebase initialization. Handle code for setup and descriptors of the USB module. Handle code for reading analog input and up-dating key state. Handle code for trigger and macro functions for the keyboard module.
Tuong Phi Tuan | Software design. Handle code for OLED display. Optimized the SSD1306 screen update rou-tine.
Tran Quang Hung | Handle code for snaptap functions. Handle code for macro functions.
3.6. Evaluation and Assessment

The system has met all defined functional and non-functional requirements and functions reliably. All core features, including analog key sensing using Hall effect sensors, dynamic actuation point handling (rapid trigger), macro function, auto calibration method and USB Composite Device communication are working as intended. The firmware handles real-time key updates efficiently, and the modular design allows for future expandability, such as additional layers and keys in the software or adding new hardwares such as rotary encoders.
However, the biggest hurdle during development was the late arrival of the PCB, which significantly delayed hardware testing and integration. This bottleneck forced much of the software development and debugging process to be done on a breadboard, resulting in limited time for full system validation once the hardware was finally available.
Another limitation is the current configuration interface, which only accepts keycodes in decimal form. While functional, this reduces usability—especially for users more familiar with symbolic key representations (e.g., KC_A, CTRL, or MEDIA_PLAY). Overall, the system demonstrates a reliable and well-structured implementation of a custom keyboard firmware. It successfully integrates analog key sensing with Hall-Effect sensors, dynamic actuation logic, macro capabilities, and USB Composite Device communication. The architecture is efficient and modular, supporting smooth real-time key updates and leaving ample room for expansion.

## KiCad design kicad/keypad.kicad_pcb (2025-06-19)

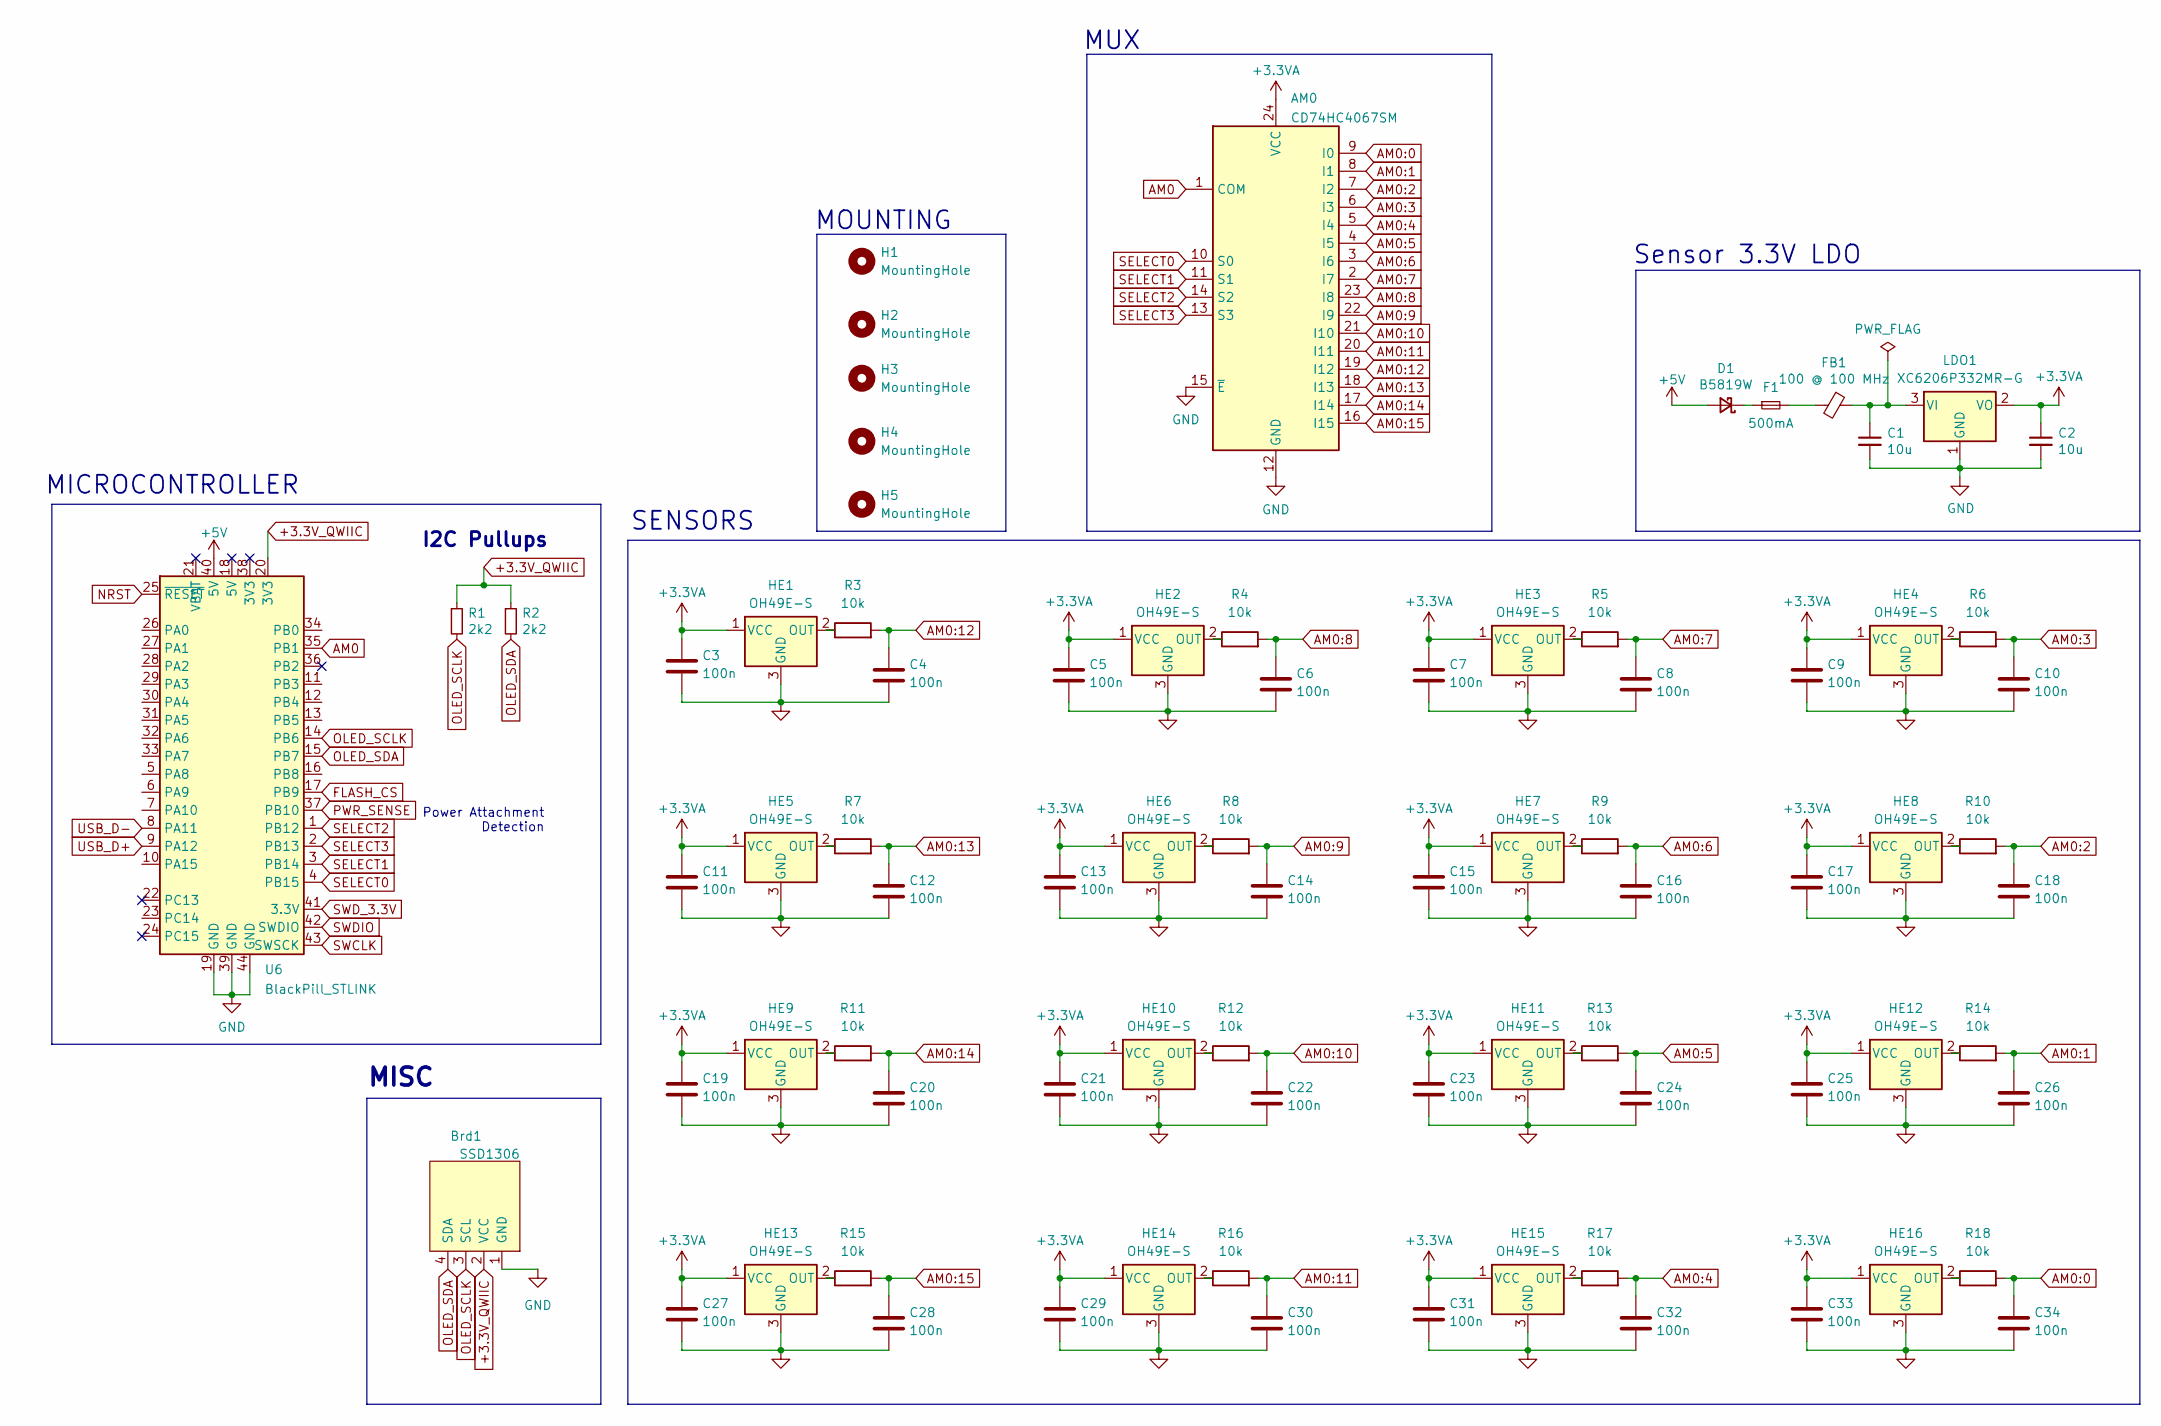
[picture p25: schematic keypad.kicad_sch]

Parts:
AM0: CD74HC4067SM; SSOP-24_5.3x8.2mm_P0.65mm
Brd1: SSD1306; 128x64OLED
C1, C2: 10u; C_0402_1005Metric; MPN CL05A106MQ5NUNC; LCSC Part C15525
C3, C4, C5, C6, C7, C8, C9, C10, C11, C12, C13, C14, C15, C16, C17, C18, C19, C20, C21, C22, C23, C24, C25, C26, C27, C28, C29, C30, C31, C32, C33, C34: 100n; C_0402_1005Metric
D1: B5819W; D_SOD-123; MPN B5819W; LCSC Part C8598
F1: 500mA; Fuse_0603_1608Metric; LCSC Part C261937
FB1: 100 @ 100 MHz; L_0805_2012Metric; MPN GZ2012D101TF; LCSC Part C1015
H1, H2, H3, H4, H5: MountingHole; MountingHole_3.2mm_M3_DIN965_Pad
HE1, HE2, HE3, HE4, HE5, HE6, HE7, HE8, HE9, HE10, HE11, HE12, HE13, HE14, HE15, HE16: OH49E-S; SW_MX_HE_0deg_1u
LDO1: XC6206P332MR-G; SOT-23-3; LCSC Part XC6206P332MR-G
R1, R2: 2k2; R_0402_1005Metric; MPN 0402WGF2201TCE; LCSC Part C25879
R3, R4, R5, R6, R7, R8, R9, R10, R11, R12, R13, R14, R15, R16, R17, R18: 10k; R_0402_1005Metric
U6: BlackPill_STLINK

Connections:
+3.3VA: AM0.24 (VCC), C2.1, C3.1, C5.1, C7.1, C9.1, C11.1, C13.1, C15.1, C17.1, C19.1, C21.1, C23.1, C25.1, C27.1, C29.1, C31.1, C33.1, HE1.1 (VCC), HE2.1 (VCC), HE3.1 (VCC), HE4.1 (VCC), HE5.1 (VCC), HE6.1 (VCC), HE7.1 (VCC), HE8.1 (VCC), HE9.1 (VCC), HE10.1 (VCC), HE11.1 (VCC), HE12.1 (VCC), HE13.1 (VCC), HE14.1 (VCC), HE15.1 (VCC), HE16.1 (VCC), LDO1.2 (VO)
+3.3V_QWIIC: Brd1.2 (VCC), R1.1, R2.1, U6.20 (3V3)
+5V: D1.2 (A), U6.40 (5V)
AM0: AM0.1 (COM), U6.35 (PB1)
AM0:0: AM0.9 (I0), C34.1, R18.2
AM0:1: AM0.8 (I1), C26.1, R14.2
AM0:2: AM0.7 (I2), C18.1, R10.2
AM0:3: AM0.6 (I3), C10.1, R6.2
AM0:4: AM0.5 (I4), C32.1, R17.2
AM0:5: AM0.4 (I5), C24.1, R13.2
AM0:6: AM0.3 (I6), C16.1, R9.2
AM0:7: AM0.2 (I7), C8.1, R5.2
AM0:8: AM0.23 (I8), C6.1, R4.2
AM0:9: AM0.22 (I9), C14.1, R8.2
AM0:10: AM0.21 (I10), C22.1, R12.2
AM0:11: AM0.20 (I11), C30.1, R16.2
AM0:12: AM0.19 (I12), C4.1, R3.2
AM0:13: AM0.18 (I13), C12.1, R7.2
AM0:14: AM0.17 (I14), C20.1, R11.2
AM0:15: AM0.16 (I15), C28.1, R15.2
FLASH_CS: U6.17 (PB9)
GND: AM0.12 (GND), AM0.15 (~E), Brd1.1 (GND), C1.2, C2.2, C3.2, C4.2, C5.2, C6.2, C7.2, C8.2, C9.2, C10.2, C11.2, C12.2, C13.2, C14.2, C15.2, C16.2, C17.2, C18.2, C19.2, C20.2, C21.2, C22.2, C23.2, C24.2, C25.2, C26.2, C27.2, C28.2, C29.2, C30.2, C31.2, C32.2, C33.2, C34.2, HE1.3 (GND), HE2.3 (GND), HE3.3 (GND), HE4.3 (GND), HE5.3 (GND), HE6.3 (GND), HE7.3 (GND), HE8.3 (GND), HE9.3 (GND), HE10.3 (GND), HE11.3 (GND), HE12.3 (GND), HE13.3 (GND), HE14.3 (GND), HE15.3 (GND), HE16.3 (GND), LDO1.1 (GND), U6.19 (GND), U6.39 (GND), U6.44 (GND)
NRST: U6.25 (~RESET)
unnamed: D1.1 (K), F1.1
unnamed: F1.2, FB1.2
unnamed: HE1.2 (OUT), R3.1
unnamed: HE2.2 (OUT), R4.1
unnamed: HE3.2 (OUT), R5.1
unnamed: HE4.2 (OUT), R6.1
unnamed: HE5.2 (OUT), R7.1
unnamed: HE6.2 (OUT), R8.1
unnamed: HE7.2 (OUT), R9.1
unnamed: HE8.2 (OUT), R10.1
unnamed: HE9.2 (OUT), R11.1
unnamed: HE10.2 (OUT), R12.1
unnamed: HE11.2 (OUT), R13.1
unnamed: HE12.2 (OUT), R14.1
unnamed: HE13.2 (OUT), R15.1
unnamed: HE14.2 (OUT), R16.1
unnamed: HE15.2 (OUT), R17.1
unnamed: HE16.2 (OUT), R18.1
unnamed: C1.1, FB1.1, LDO1.3 (VI)
OLED_SCLK: Brd1.3 (SCL), R1.2, U6.14 (PB6)
OLED_SDA: Brd1.4 (SDA), R2.2, U6.15 (PB7)
PWR_SENSE: U6.37 (PB10)
SELECT0: AM0.10 (S0), U6.4 (PB15)
SELECT1: AM0.11 (S1), U6.3 (PB14)
SELECT2: AM0.14 (S2), U6.1 (PB12)
SELECT3: AM0.13 (S3), U6.2 (PB13)
SWCLK: U6.43 (SWSCK)
SWDIO: U6.42 (SWDIO)
SWD_3.3V: U6.41 (3.3V)
USB_D+: U6.9 (PA12)
USB_D-: U6.8 (PA11)

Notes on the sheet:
Power Attachment Detection
MUX
I2C Pullups
SENSORS
Sensor 3.3V LDO
MOUNTING
MICROCONTROLLER
MISC

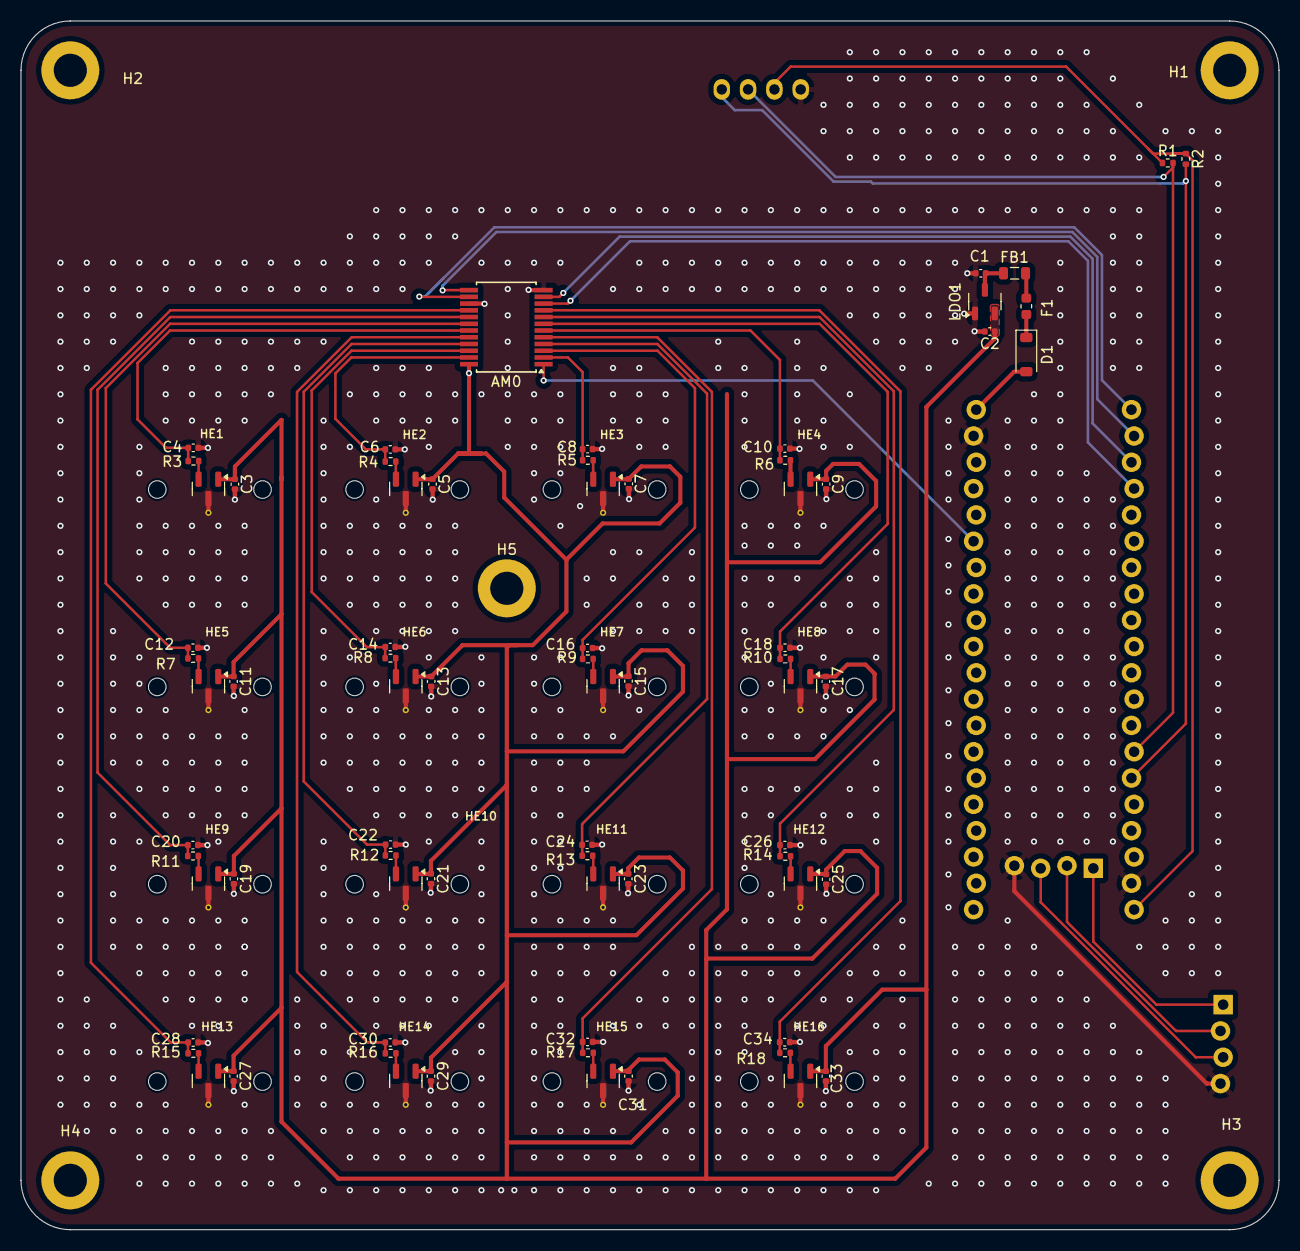
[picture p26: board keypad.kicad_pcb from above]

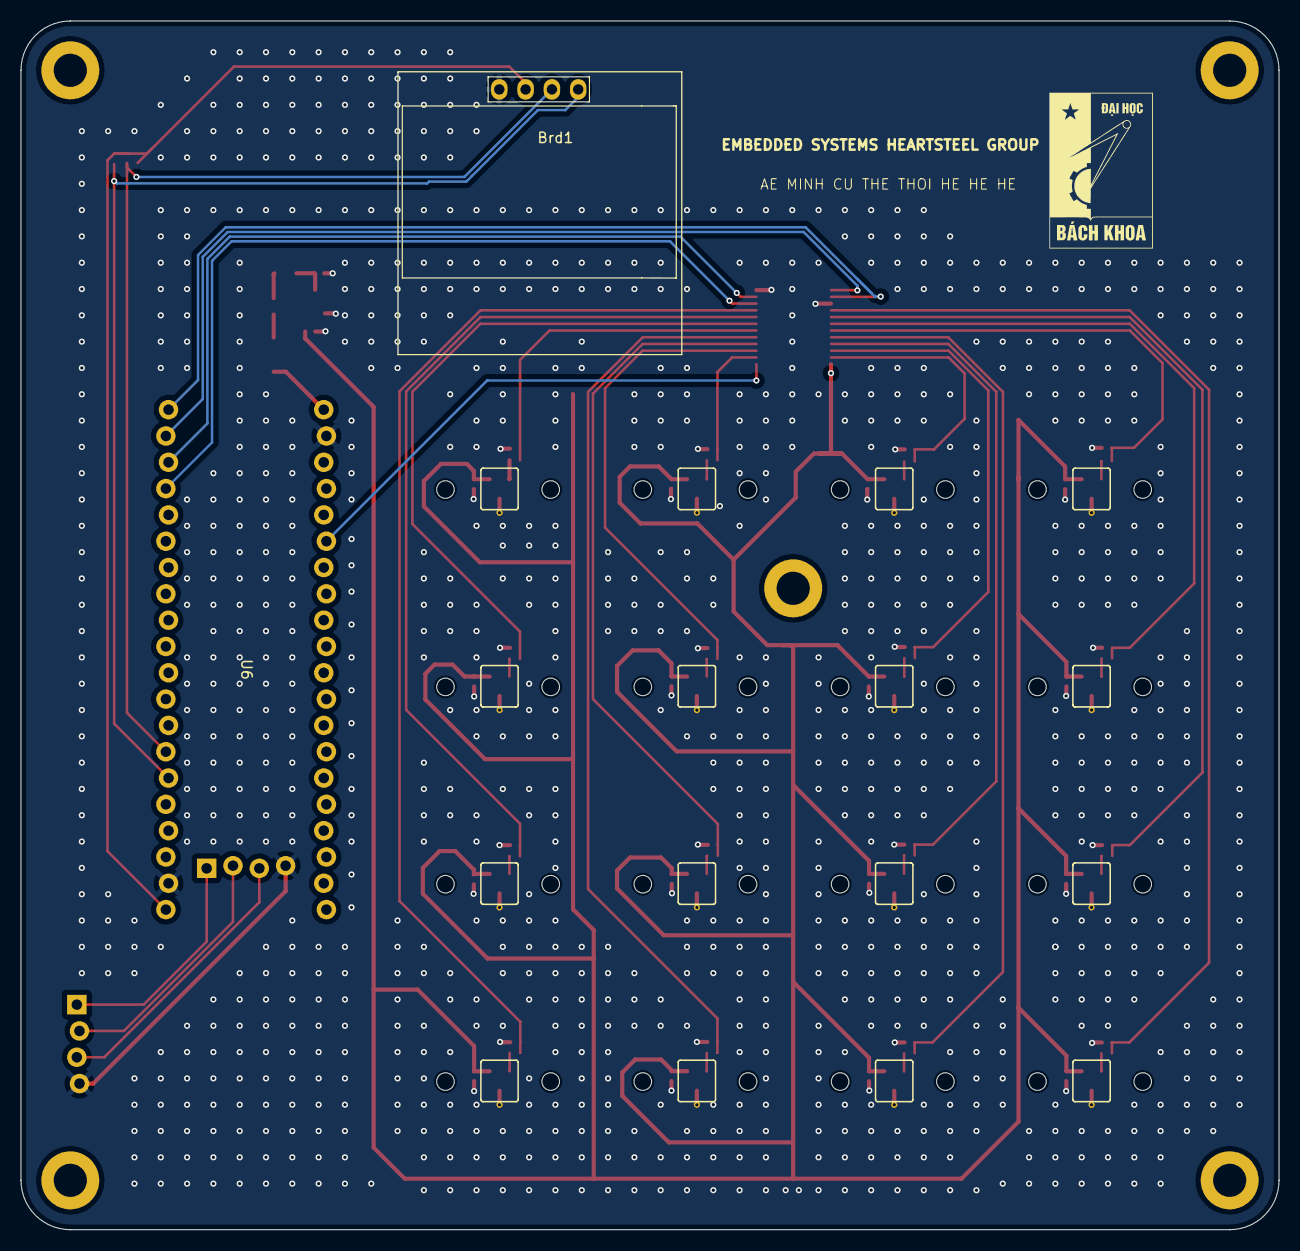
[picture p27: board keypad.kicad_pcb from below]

Board: 2 copper layers, 121.4 x 116.7 mm, 80 parts (2 on the bottom side), 46 nets.

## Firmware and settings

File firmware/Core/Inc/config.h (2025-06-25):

#ifndef __CONFIG_H
#define __CONFIG_H

#include <stdint.h>

#define DEFAULT_REVERSE_MAGNET_POLE 0
#define DEFAULT_TRIGGER_OFFSET 64
#define DEFAULT_RESET_THRESHOLD 3
#define DEFAULT_RAPID_TRIGGER_OFFSET 40
#define DEFAULT_TAP_TIMEOUT 200
#define MAX_MACRO_LEN 4
#define ADC_CHANNEL_COUNT 1
#define AMUX_SELECT_PINS_COUNT 4
#define AMUX_CHANNEL_COUNT 16

#define MATRIX_ROWS 4
#define MATRIX_COLS 4

extern const struct user_config keyboard_default_user_config;
extern const uint8_t channels_by_row_col[MATRIX_ROWS][MATRIX_COLS][2];

#endif /* __CONFIG_H */

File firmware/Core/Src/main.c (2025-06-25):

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
/* Includes ------------------------------------------------------------------*/
#include "main.h"

/* USER CODE BEGIN Includes */
#include "config.h"
#include "hid.h"
#include "keyboard.h"
#include "ssd1306.h"
#include "ssd1306_conf.h"
#include "ssd1306_fonts.h"
#include "tusb.h"
#include <cdc.h>
#include <ctype.h>
/* USER CODE END Includes */

/* USER CODE BEGIN PD */

#define MOD_WIDTH 38
#define KEY_WIDTH ((SSD1306_WIDTH - MOD_WIDTH) / 3)
#define DIVIDER 32

/* USER CODE END PD */

ADC_HandleTypeDef hadc1;

I2C_HandleTypeDef hi2c1;

PCD_HandleTypeDef hpcd_USB_OTG_FS;

/* USER CODE BEGIN PV */
ADC_ChannelConfTypeDef ADC_channel_Config = {0};

extern struct user_config keyboard_user_config;

const uint32_t adc_channels[ADC_CHANNEL_COUNT] = {ADC_CHANNEL_9};
const uint32_t amux_select_pins[AMUX_SELECT_PINS_COUNT] = {GPIO_PIN_15, GPIO_PIN_14, GPIO_PIN_12, GPIO_PIN_13};

extern struct key keyboard_keys[ADC_CHANNEL_COUNT][AMUX_CHANNEL_COUNT];

// Add global mode variable
keyboard_mode_t g_keyboard_mode = MODE_COMBO_KEY;
uint8_t last_mode_key_pressed = 0;
uint8_t last_layer_key_pressed = 0;
// Thêm biến toàn cục lưu layer hiện tại
int current_layer = _BASE_LAYER;
/* USER CODE END PV */

void SystemClock_Config(void);
static void MX_GPIO_Init(void);
static void MX_ADC1_Init(void);
static void MX_USB_OTG_FS_PCD_Init(void);
static void MX_I2C1_Init(void);
/* USER CODE BEGIN 0 */
uint8_t cycle_count_on = 0;
/* USER CODE END 0 */

/**
 * @brief  The application entry point.
 * @retval int
 */
int main(void) {
  /* MCU Configuration--------------------------------------------------------*/

  /* Reset of all peripherals, Initializes the Flash interface and the Systick. */
  HAL_Init();

  /* Configure the system clock */
  SystemClock_Config();

  /* Initialize all configured peripherals */
  MX_GPIO_Init();
  MX_ADC1_Init();
  MX_USB_OTG_FS_PCD_Init();
  MX_I2C1_Init();
  /* USER CODE BEGIN 2 */

  ADC_channel_Config.Rank = 1;
  ADC_channel_Config.SamplingTime = ADC_SAMPLETIME_3CYCLES;

  keyboard_init_keys();
  ssd1306_Init();
  tusb_rhport_init_t dev_init = {
      .role = TUSB_ROLE_DEVICE,
      .speed = TUSB_SPEED_AUTO};
  tusb_init(0, &dev_init); // initialize device stack on roothub port 0
  /* USER CODE END 2 */

  /* Infinite loop */
  /* USER CODE BEGIN WHILE */
  uint32_t start_at;

  while (1) {
    // MARK: Main loop
    start_at = HAL_GetTick();
    tud_task();

    struct key *mode_key = NULL;
    struct key *layer_key = NULL;
    for (int adc = 0; adc < ADC_CHANNEL_COUNT; ++adc) {
      for (int amux = 0; amux < AMUX_CHANNEL_COUNT; ++amux) {
        struct key *k = &keyboard_keys[adc][amux];
        if (k->layers[_BASE_LAYER].value[0] == HID_MODE_CHANGE) {
          mode_key = k;
        }
        if (k->layers[_BASE_LAYER].value[0] == HID_LAYER_CHANGE) {
          layer_key = k;
        }
      }
    }
    uint8_t mode_key_pressed = (mode_key && mode_key->actuation.status == STATUS_TRIGGERED);
    uint8_t layer_key_pressed = (layer_key && layer_key->actuation.status == STATUS_TRIGGERED);
    if (mode_key_pressed && !last_mode_key_pressed) {
      g_keyboard_mode = (g_keyboard_mode == MODE_COMBO_KEY) ? MODE_SNAP_TAP : MODE_COMBO_KEY;
      if (g_keyboard_mode == MODE_COMBO_KEY) {
        tud_cdc_write_str("Mode: COMBO_KEY\r\n");
      } else {
        tud_cdc_write_str("Mode: SNAP_TAP\r\n");
      }
      tud_cdc_write_flush();
    }
    if (layer_key_pressed && !last_layer_key_pressed) {
      // Toggle tuần tự giữa BASE, ALT, ALT2
      if (current_layer == _BASE_LAYER) {
        current_layer = _ALT_LAYER;
        tud_cdc_write_str("Layer: ALT\r\n");
      } else if (current_layer == _ALT_LAYER) {
        current_layer = _ALT_LAYER_2;
        tud_cdc_write_str("Layer: ALT2\r\n");
      } else {
        current_layer = _BASE_LAYER;
        tud_cdc_write_str("Layer: BASE\r\n");
      }
      tud_cdc_write_flush();
    }
    last_mode_key_pressed = mode_key_pressed;
    last_layer_key_pressed = layer_key_pressed;

    // Call the appropriate task based on mode
    if (g_keyboard_mode == MODE_COMBO_KEY) {
      keyboard_task();
    } else {
      snaptap_task();
    }
    //    snaptap_task();
    //    keyboard_task();

    hid_task();
    cdc_task();

    ssd1306_Fill(White);
    ssd1306_FlipScreen(1, 1);

    ssd1306_DrawRectangle(0, 0, SSD1306_WIDTH - 1, SSD1306_HEIGHT - 1, Black);
    ssd1306_Line(MOD_WIDTH, DIVIDER, SSD1306_WIDTH - 1, DIVIDER, Black);
    ssd1306_Line(MOD_WIDTH, 0, MOD_WIDTH, SSD1306_HEIGHT - 1, Black);
    for (int i = 1; i < 3; i++) {
      int x = MOD_WIDTH + i * KEY_WIDTH;
      ssd1306_Line(x, 0, x, SSD1306_HEIGHT - 1, Black);
    }

    int mod_y = 2;
    const int mod_line_height = 10;

    int label_row_bot = SSD1306_HEIGHT - DIVIDER + 2;
    int percent_row_bot = SSD1306_HEIGHT - 8 - 2;

    int label_row_top = 2;
    int percent_row_top = label_row_bot - 11;

    char keycodes[6][2] = {0};
    uint8_t key_percents[6] = {0};
    int tracker = 0;

    for (int amux = 0; amux < AMUX_CHANNEL_COUNT; amux++) {
      struct key *k = &keyboard_keys[0][amux];

      if (k->state.filtered_distance_8bits >= 15 && k->layers[current_layer].type == KEY_TYPE_MODIFIER) {
        uint16_t bitmask = *(uint16_t *)k->layers[current_layer].value;
        const char *label = NULL;

        if (bitmask == 0b00000001)
          label = "LCtrl";
        else if (bitmask == 0b00000010)
          label = "LShift";
        else if (bitmask == 0b00000100)
          label = "LAlt";
        else if (bitmask == 0b00001000)
          label = "LGUI";
        else if (bitmask == 0b00010000)
          label = "RCtrl";
        else if (bitmask == 0b00100000)
          label = "RShift";
        else if (bitmask == 0b01000000)
          label = "RAlt";
        else if (bitmask == 0b10000000)
          label = "RGUI";

        if (label) {
          ssd1306_SetCursor(2, mod_y);
          ssd1306_WriteString(label, Font_6x8, Black);
          mod_y += mod_line_height;
        }
      }

      else if (k->state.filtered_distance_8bits >= 15 && tracker < 6 && k->layers[current_layer].type == KEY_TYPE_NORMAL) {
        uint16_t keycode = k->layers[current_layer].value[0];
        if (keycode >= 0x04 && keycode <= 0x1D) {
          keycodes[tracker][0] = 'A' + (keycode - 0x04);
          keycodes[tracker][1] = '\0';
        } else if (keycode >= 0x1E && keycode <= 0x27) {
          keycodes[tracker][0] = (keycode == 0x27) ? '0' : ('1' + (keycode - 0x1E));
          keycodes[tracker][1] = '\0';
        }

        key_percents[tracker] = (k->state.filtered_distance_8bits * 100) / 254;
        tracker++;
      }
    }

    for (int i = 1; i <= 3; i++) {
      if (keycodes[i - 1][0] != '\0') {
        int x = MOD_WIDTH + (i - 1) * KEY_WIDTH + 4;
        ssd1306_SetCursor(x, label_row_top);
        ssd1306_WriteString((char *)keycodes[i - 1], Font_6x8, Black);

        char buf[6];
        sprintf(buf, "%d%%", key_percents[i - 1]);
        ssd1306_SetCursor(x, percent_row_top);
        ssd1306_WriteString(buf, Font_6x8, Black);
      }
    }

    for (int i = 4; i <= 6; i++) {
      if (keycodes[i - 1][0] != '\0') {
        int x = MOD_WIDTH + (i - 4) * KEY_WIDTH + 4;
        ssd1306_SetCursor(x, label_row_bot);
        ssd1306_WriteString((char *)keycodes[i - 1], Font_6x8, Black);

        char buf[6];
        sprintf(buf, "%d%%", key_percents[i - 1]);
        ssd1306_SetCursor(x, percent_row_bot);
        ssd1306_WriteString(buf, Font_6x8, Black);
      }
    }

    ssd1306_UpdateScreen();
    if (cycle_count_on) {
      cdc_performance_measure(start_at);
    }
    /* USER CODE END WHILE */

    /* USER CODE BEGIN 3 */
  }
  /* USER CODE END 3 */
}

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
/* USER CODE BEGIN 4 */

// MARK: keyboard_* functions

void keyboard_read_config() {
  memcpy(&keyboard_user_config, (uint32_t *)CONFIG_ADDRESS, sizeof(keyboard_user_config));
}

uint8_t keyboard_write_config(uint8_t *buffer, uint16_t offset, uint16_t size) {
  if (offset >= sizeof(keyboard_user_config)) {
    return 0;
  }

  HAL_FLASH_Unlock();
  __HAL_FLASH_CLEAR_FLAG(FLASH_FLAG_EOP | FLASH_FLAG_OPERR | FLASH_FLAG_WRPERR | FLASH_FLAG_PGAERR | FLASH_FLAG_PGSERR);
  FLASH_Erase_Sector(FLASH_SECTOR_6, VOLTAGE_RANGE_3);
  for (uint16_t i = offset; i < size; i++) {
    if (HAL_FLASH_Program(FLASH_TYPEPROGRAM_BYTE, CONFIG_ADDRESS + i, buffer[i]) != HAL_OK) {
      HAL_FLASH_Lock();
    };
  }
  HAL_FLASH_Lock();
  return 1;
}

void keyboard_select_amux(uint8_t amux_channel) {
  // TODO: set GPIOs at the same time using bitmap on register
  for (uint8_t i = 0; i < AMUX_SELECT_PINS_COUNT; i++) {
    HAL_GPIO_WritePin(GPIOB, amux_select_pins[i], (amux_channel >> i) & 1);
  }
}

void keyboard_select_adc(uint8_t adc_channel) {
  ADC_channel_Config.Channel = adc_channels[adc_channel];
  HAL_ADC_ConfigChannel(&hadc1, &ADC_channel_Config);
  HAL_ADC_Start(&hadc1);
  HAL_ADC_PollForConversion(&hadc1, 1);
}

uint16_t keyboard_read_adc() {
  return HAL_ADC_GetValue(&hadc1);
}

void keyboard_close_adc() {
  HAL_ADC_Stop(&hadc1);
}

uint32_t keyboard_get_time() {
  return HAL_GetTick();
}

/* USER CODE END 4 */
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


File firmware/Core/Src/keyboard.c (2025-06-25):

#include "keyboard.h"
#include "hid.h"
#include <class/hid/hid.h>
#include <stdio.h>
#include <stdlib.h>

struct key keyboard_keys[ADC_CHANNEL_COUNT][AMUX_CHANNEL_COUNT] = {0};
struct user_config keyboard_user_config = {
    .reverse_magnet_pole = 0,
    .trigger_offset = 150,
    .reset_threshold = 3,
    .rapid_trigger_offset = 40,
    .tap_timeout = 200,
    .keymaps = {
        // clang-format off
		        [_BASE_LAYER] = {
								{{HID_KEY_0}, {HID_KEY_1}, {HID_KEY_2}, {HID_KEY_3}},
    			                {{HID_KEY_4}, {HID_KEY_5}, {HID_KEY_6}, {HID_KEY_7}},
    			                {{HID_KEY_8}, {HID_KEY_9}, {HID_KEY_A}, {HID_KEY_D}},
    			                {{HID_KEY_CONTROL_LEFT}, {HID_KEY_SHIFT_LEFT}, {HID_LAYER_CHANGE}, {HID_MODE_CHANGE}},
    			            },
            [_TAP_LAYER] = {
							  {{____}, {____}, {____}, {____}},
                {{____}, {____}, {____}, {____}},
                {{____}, {____}, {____}, {____}},
                {{____}, {____}, {____}, {____}},
            },
            [_ALT_LAYER] = {
                {{HID_KEY_A}, {HID_KEY_B}, {HID_KEY_C}, {HID_KEY_D}},
                {{HID_KEY_E}, {HID_KEY_F}, {HID_KEY_G}, {HID_KEY_H}},
                {{HID_KEY_J}, {HID_KEY_K}, {HID_KEY_L}, {HID_KEY_M}},
                {{HID_KEY_CONTROL_LEFT}, {HID_KEY_SHIFT_LEFT}, {HID_LAYER_CHANGE}, {HID_MODE_CHANGE}},
            },
            [_ALT_LAYER_2] = {
                { {HID_KEY_N}, {HID_KEY_O}, {HID_KEY_P}, {HID_KEY_Q} },
                { {HID_KEY_R}, {HID_KEY_S}, {HID_KEY_T}, {HID_KEY_U} },
                { {HID_KEY_V}, {HID_KEY_W}, {HID_KEY_X}, {HID_KEY_Y} },
                { {HID_KEY_Z}, {HID_KEY_CONTROL_LEFT}, {HID_LAYER_CHANGE}, {HID_MODE_CHANGE} },
            },
        // clang-format on
    }};

uint32_t keyboard_last_cycle_duration = 0;

static uint8_t key_triggered = 0;

struct key *current_pressed_key = NULL;

uint8_t get_bitmask_for_modifier(uint8_t keycode) {
  switch (keycode) {
  case HID_KEY_CONTROL_LEFT:
    return 0b00000001;
  case HID_KEY_SHIFT_LEFT:
    return 0b00000010;
  case HID_KEY_ALT_LEFT:
    return 0b00000100;
  case HID_KEY_GUI_LEFT:
    return 0b00001000;
  case HID_KEY_CONTROL_RIGHT:
    return 0b00010000;
  case HID_KEY_SHIFT_RIGHT:
    return 0b00100000;
  case HID_KEY_ALT_RIGHT:
    return 0b01000000;
  case HID_KEY_GUI_RIGHT:
    return 0b10000000;
  default:
    return 0b00000000;
  }
}

uint16_t get_usage_consumer_control(uint16_t value) {
  if (value > 0xFF) {
    return value & 0b0111111111111111;
  } else {
    return 0;
  }
}

void init_key(uint8_t adc_channel, uint8_t amux_channel, uint8_t row, uint8_t column) {

  struct key *key = &keyboard_keys[adc_channel][amux_channel];

  key->is_enabled = 1;
  key->is_idle = 0;
  key->row = row;
  key->column = column;

  key->calibration.cycles_count = 0;
  key->calibration.idle_value = IDLE_VALUE_APPROX;
  key->calibration.max_distance = MAX_DISTANCE_APPROX;

  key->actuation.status = STATUS_RESET;
  key->actuation.trigger_offset = keyboard_user_config.trigger_offset;
  key->actuation.reset_offset = keyboard_user_config.trigger_offset - keyboard_user_config.reset_threshold;
  key->actuation.rapid_trigger_offset = keyboard_user_config.rapid_trigger_offset;

  for (uint8_t i = 0; i < LAYERS_COUNT; i++) {
    if (keyboard_user_config.keymaps[i][row][column][0] != ____) {
      // Check if this is a macro (multiple non-zero elements)
      uint8_t macro_count = 0;
      for (uint8_t j = 0; j < MAX_MACRO_LEN; j++) {
        if (keyboard_user_config.keymaps[i][row][column][j] != ____) {
          macro_count++;
        }
      }

      if (macro_count > 1) {
        // This is a macro - copy all values
        key->layers[i].type = KEY_TYPE_MACRO;
        for (uint8_t j = 0; j < MAX_MACRO_LEN; j++) {
          key->layers[i].value[j] = keyboard_user_config.keymaps[i][row][column][j];
        }
      } else {
        // Single key - check type
        uint16_t usage_consumer_control = get_usage_consumer_control(
            keyboard_user_config.keymaps[i][row][column][0]);
        if (usage_consumer_control) {
          key->layers[i].type = KEY_TYPE_CONSUMER_CONTROL;
          key->layers[i].value[0] = usage_consumer_control;
        } else {
          uint8_t bitmask = get_bitmask_for_modifier(
              keyboard_user_config.keymaps[i][row][column][0]);
          if (bitmask) {
            key->layers[i].type = KEY_TYPE_MODIFIER;
            key->layers[i].value[0] = bitmask;
          } else {
            key->layers[i].type = KEY_TYPE_NORMAL;
            key->layers[i].value[0] =
                keyboard_user_config.keymaps[i][row][column][0];
          }
        }
      }
    }
  }
}
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

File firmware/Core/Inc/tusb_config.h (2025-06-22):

#ifndef _TUSB_CONFIG_H_
#define _TUSB_CONFIG_H_

#ifdef __cplusplus
extern "C" {
#endif

//--------------------------------------------------------------------
// COMMON CONFIGURATION
//--------------------------------------------------------------------

// defined by compiler flags for flexibility
#define CFG_TUSB_MCU OPT_MCU_STM32F4
#ifndef CFG_TUSB_MCU
  #error CFG_TUSB_MCU must be defined
#endif

// RHPort number used for device can be defined by board.mk, default to port 0
#ifndef BOARD_DEVICE_RHPORT_NUM
  #define BOARD_DEVICE_RHPORT_NUM     0
#endif

// RHPort max operational speed can defined by board.mk
// Default to Highspeed for MCU with internal HighSpeed PHY (can be port specific), otherwise FullSpeed
#ifndef BOARD_DEVICE_RHPORT_SPEED
  #define BOARD_DEVICE_RHPORT_SPEED   OPT_MODE_DEFAULT_SPEED
#endif

// Device mode with rhport and speed defined by board.mk
#if   BOARD_DEVICE_RHPORT_NUM == 0
  #define CFG_TUSB_RHPORT0_MODE     (OPT_MODE_DEVICE | BOARD_DEVICE_RHPORT_SPEED)
#elif BOARD_DEVICE_RHPORT_NUM == 1
  #define CFG_TUSB_RHPORT1_MODE     (OPT_MODE_DEVICE | BOARD_DEVICE_RHPORT_SPEED)
#else
  #error "Incorrect RHPort configuration"
#endif

#ifndef CFG_TUSB_OS
  #define CFG_TUSB_OS               OPT_OS_NONE
#endif

#ifndef CFG_TUSB_DEBUG
  #define CFG_TUSB_DEBUG            0
#endif

// Enable Device stack
#define CFG_TUD_ENABLED             1

// Default is max speed that hardware controller could support with on-chip PHY
#define CFG_TUD_MAX_SPEED           BOARD_DEVICE_RHPORT_SPEED

//--------------------------------------------------------------------
// DEVICE CONFIGURATION
//--------------------------------------------------------------------

#ifndef CFG_TUD_ENDPOINT0_SIZE
  #define CFG_TUD_ENDPOINT0_SIZE    64
#endif

//------------- CLASS -------------//
#define CFG_TUD_HID               1
#define CFG_TUD_CDC               1
#define CFG_TUD_MSC               0
#define CFG_TUD_MIDI              0
#define CFG_TUD_VENDOR            0

// HID buffer size Should be sufficient to hold ID (if any) + Data
#define CFG_TUD_HID_EP_BUFSIZE    16

// CDC FIFO size of TX and RX
#define CFG_TUD_CDC_RX_BUFSIZE    64
#define CFG_TUD_CDC_TX_BUFSIZE    128

// CDC Endpoint transfer buffer size, more is faster
#define CFG_TUD_CDC_EP_BUFSIZE    64

#ifdef __cplusplus
}
#endif

#endif /* _TUSB_CONFIG_H_ */

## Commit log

2025-06-08 upadate kicad pcb
    [Embedded_Project.kicad_pcb, Embedded_Project.kicad_sch, Embedded_Project_REV_1.kicad_pcb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]
2025-06-11 finished 4x4 pcb design
    [Embedded_Project.kicad_pcb, Embedded_Project.kicad_sch, Embedded_Project_REV_1.kicad_pcb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]
2025-06-19 Implement SnapTap logic and debug for keyboard
    [keyboard.c]
2025-06-21 added usb descriptors for cdc + hid composite device and add utils to read COM ports on windows
2025-06-23 display optimization and fixed modifier display
    [cdc.c, main.c]
2025-06-25 updated minor errors
    [keypad.kicad_sch]

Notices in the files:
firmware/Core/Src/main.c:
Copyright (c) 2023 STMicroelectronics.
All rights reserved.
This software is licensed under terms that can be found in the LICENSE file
